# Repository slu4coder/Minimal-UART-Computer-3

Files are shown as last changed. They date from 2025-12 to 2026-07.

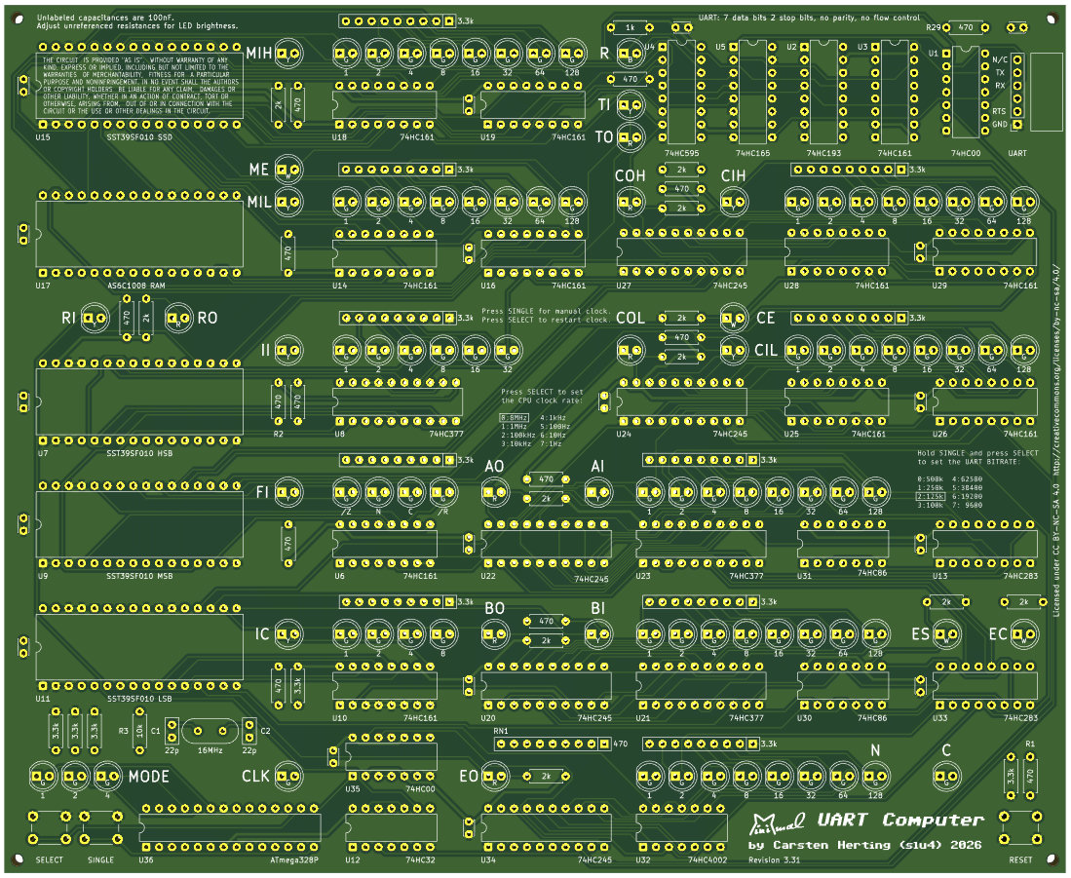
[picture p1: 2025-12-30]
Layout.jpg

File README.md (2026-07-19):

# Minimal UART Computer 3 - Blinkenlights!

Here comes a big update of my DIY 'Minimal UART Computer', a machine built around a serial interface just from a handful of logic ICs, RAM and FLASH memory. For it's size, simplicity and self-imposed limitations, it's got double the processing power of a Commodore C64 or Apple II. It's mission is to be a fun learning platform for understanding computers on a fundamental level.

Minimal_UART_3

This is a free and non-commercial project. I am in no way associated with any activies selling the 'Minimal UART Computer' as a product. Any such activity represents a license violation. Individual licenses apply for hardware and software parts. Please refer to the applicable documentations for detailed licensing information. 

● Manual: https://docs.google.com/document/d/1nIM-WRrVe7SzYY-DS1jcVHC4TCuIhlQ6LCHnZnEml7k/edit?usp=sharing

● The Minimal UART Computer has a dedicated hardware serial 'Minimal Terminal': https://github.com/slu4coder/Minimal-Terminal
but can also be operated via a USB-to-serial breakout board and a terminal emulation (e. g. Tera Term) of cause.
  
OVERVIEW:

● Textbook 'Von-Neumann' architecture, 8-bit data bus, 16-bit address bus

● 64 instructions (conditional branching, subroutines, stack and word operations)

● 32KB RAM, 32KB SSD with file system (format, load, save, dir, delete, defrag, ...)

● Adjustable UART I/O (7 data bits, 2 stop bits, 9600bps – 500000bps)

● Adjustable CPU clock speed (single step – 8MHz)

● Processing power ~1.1Mips @ 8MHz comparable to 2x Commodore 64 or 2x Apple II

● Clear(est?) and simple(st? – you judge!) design

● ALU with 2 data registers A & B

● 3 flags (zero, negative, carry)

● 24 control signals

● Only 30(!) 74HCxx logic ICs, RAM and FLASH (an ATmega328p is used as a variable clock generator)

● NEW: Blinkenlights ;-)

● Operating system wiht native assembler and editor

● Games and demos (Tetris, Mandelbrot)

● Cycle-exact emulator, cross-assembler (Win64 and Linux)

I hope you find this information useful, educational or otherwise interesting. I'd love to hear about your build, so meet me on YouTube:

https://www.youtube.com/watch?v=wpls_rTcvJ8

https://www.youtube.com/channel/UCXYQcMpUBT3aaQKfmAVJNow

This is a free and non-commercial project. I am in no way associated with any activies selling this as a product.
Any such activity represents a license violation. Individual licenses apply for hardware and software parts. Please refer to the
appropriate documentations for detailed licensing information.

See https://github.com/slu4coder/Minimal-64x4-Home-Computer for a more feature-rich alternative with bitmap graphics, VGA and PS/2.

If you like this project and want to give something back, you can do so via PayPal. Thanks!

https://paypal.me/CarstenHerting

Have fun!

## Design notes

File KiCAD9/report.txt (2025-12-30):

Plot in "/home/slu4/Dokumente/KiCAD/Minimal CPU 3.3 Tiny LED KiCAD9/gerbers/8-Bit CPU 32k-F_Cu.gtl" geschrieben.
Plot in "/home/slu4/Dokumente/KiCAD/Minimal CPU 3.3 Tiny LED KiCAD9/gerbers/8-Bit CPU 32k-B_Cu.gbl" geschrieben.
Plot in "/home/slu4/Dokumente/KiCAD/Minimal CPU 3.3 Tiny LED KiCAD9/gerbers/8-Bit CPU 32k-F_Silkscreen.gto" geschrieben.
Plot in "/home/slu4/Dokumente/KiCAD/Minimal CPU 3.3 Tiny LED KiCAD9/gerbers/8-Bit CPU 32k-B_Silkscreen.gbo" geschrieben.
Plot in "/home/slu4/Dokumente/KiCAD/Minimal CPU 3.3 Tiny LED KiCAD9/gerbers/8-Bit CPU 32k-F_Mask.gts" geschrieben.
Plot in "/home/slu4/Dokumente/KiCAD/Minimal CPU 3.3 Tiny LED KiCAD9/gerbers/8-Bit CPU 32k-B_Mask.gbs" geschrieben.
Plot in "/home/slu4/Dokumente/KiCAD/Minimal CPU 3.3 Tiny LED KiCAD9/gerbers/8-Bit CPU 32k-Edge_Cuts.gm1" geschrieben.
Hinweis: Fertig.
Hinweis: Fertig.

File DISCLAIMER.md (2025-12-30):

IN THE FOLLOWING, ALL INFORMATION MADE AVAILABLE IN THIS REPOSITORY
'Minimal-UART-Computer-3' IS SUMMARIZED UNDER THE TERM "SOFTWARE".

THE SOFTWARE IS PROVIDED "AS IS", WITHOUT WARRANTY OF ANY KIND, EXPRESS OR
IMPLIED, INCLUDING BUT NOT LIMITED TO THE WARRANTIES OF MERCHANTABILITY,
FITNESS FOR A PARTICULAR PURPOSE AND NONINFRINGEMENT. IN NO EVENT SHALL THE
AUTHORS BE LIABLE FOR ANY CLAIM, DAMAGES OR OTHER LIABILITY, WHETHER IN AN
ACTION OF CONTRACT, TORT OR OTHERWISE, ARISING FROM, OUT OF OR IN CONNECTION
WITH THE SOFTWARE OR THE USE OR OTHER DEALINGS IN THE SOFTWARE.

THE 'Minimal-UART-Computer-3' MIGHT UNINTENTIONALLY INTERFERE WITH RADIO
SIGNALS OR DISTURB OTHER ELECTRONIC DEVICES. USE THIS DEVICE FOR EDUCATIONAL
PURPOSES ONLY AND DON’T EMBED IT IN ANOTHER PRODUCT.

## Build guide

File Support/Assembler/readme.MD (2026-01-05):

See 'Emulator/src' section for assembler source code 'asm.cpp' and 'asm.h'.

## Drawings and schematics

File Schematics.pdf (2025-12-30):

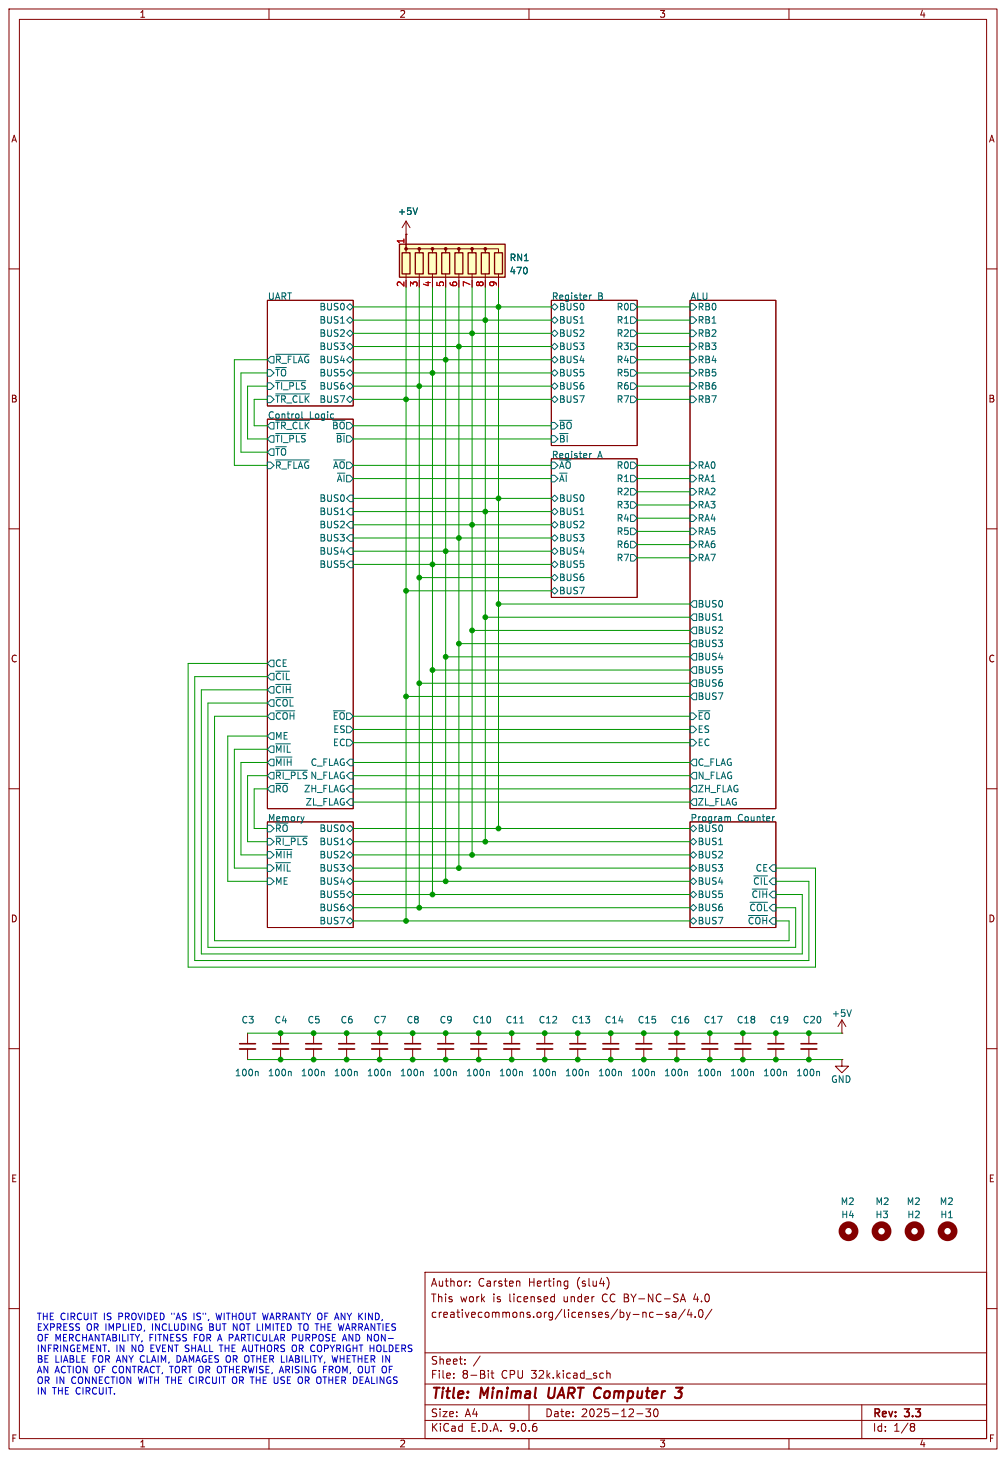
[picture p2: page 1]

~{COL} BUS3 BUS1 BUS0 BUS2 BUS4 BUS6 BUS7 BUS5 Program Counter BUS0 BUS1 BUS2 BUS3 BUS4 BUS5 BUS6 BUS7 ~{AI}

100n THE CIRCUIT IS PROVIDED "AS IS", WITHOUT WARRANTY OF ANY KIND, EXPRESS OR IMPLIED, INCLUDING BUT NOT LIMITED TO THE WARRANTIES OF MERCHANTABILITY, FITNESS FOR A PARTICULAR PURPOSE AND NON-

INFRINGEMENT. IN NO EVENT SHALL THE AUTHORS OR COPYRIGHT HOLDERS
BE LIABLE FOR ANY CLAIM, DAMAGES OR OTHER LIABILITY, WHETHER IN
AN ACTION OF CONTRACT, TORT OR OTHERWISE, ARISING FROM, OUT OF OR IN CONNECTION WITH THE CIRCUIT OR THE USE OR OTHER DEALINGS

Id: 1/8 Title: Minimal UART Computer 3

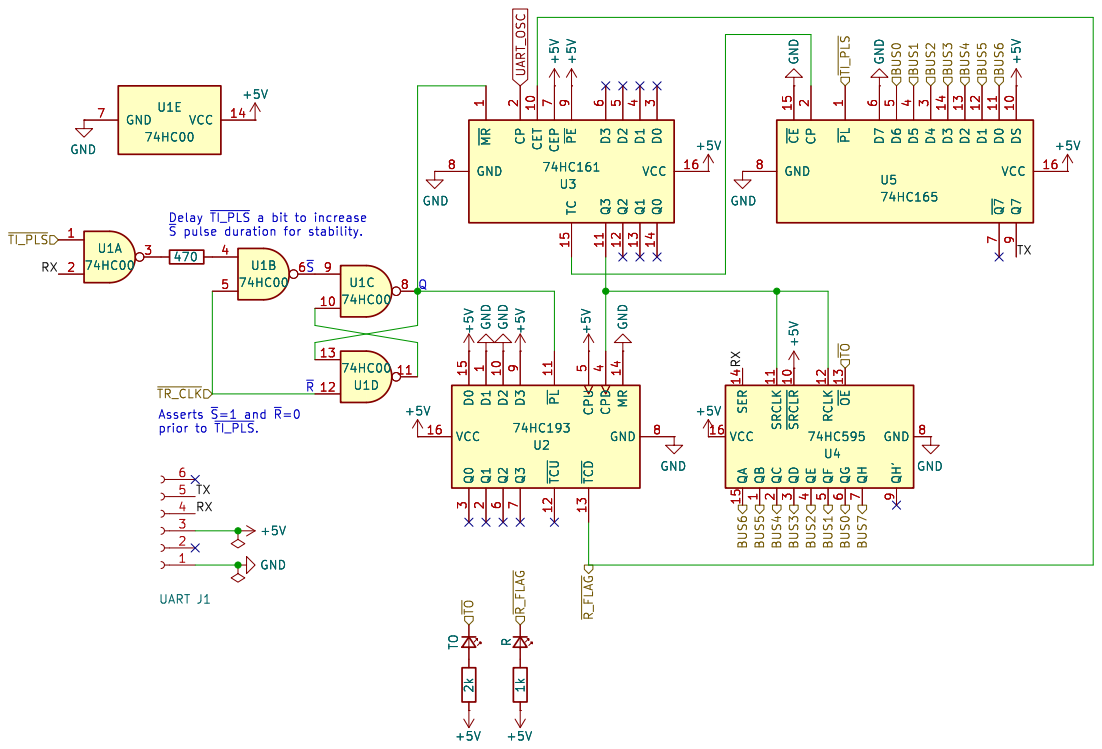
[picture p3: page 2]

2 ~{MR} 1 VCC 16 GND 8 Q0 14 Q1 13 Q2 12 Q3 11 TC 15 GND GND

2 ~{MR} 1 VCC 16 GND 8 Q0 14 Q1 13 Q2 12 Q3 11 TC 15 U3

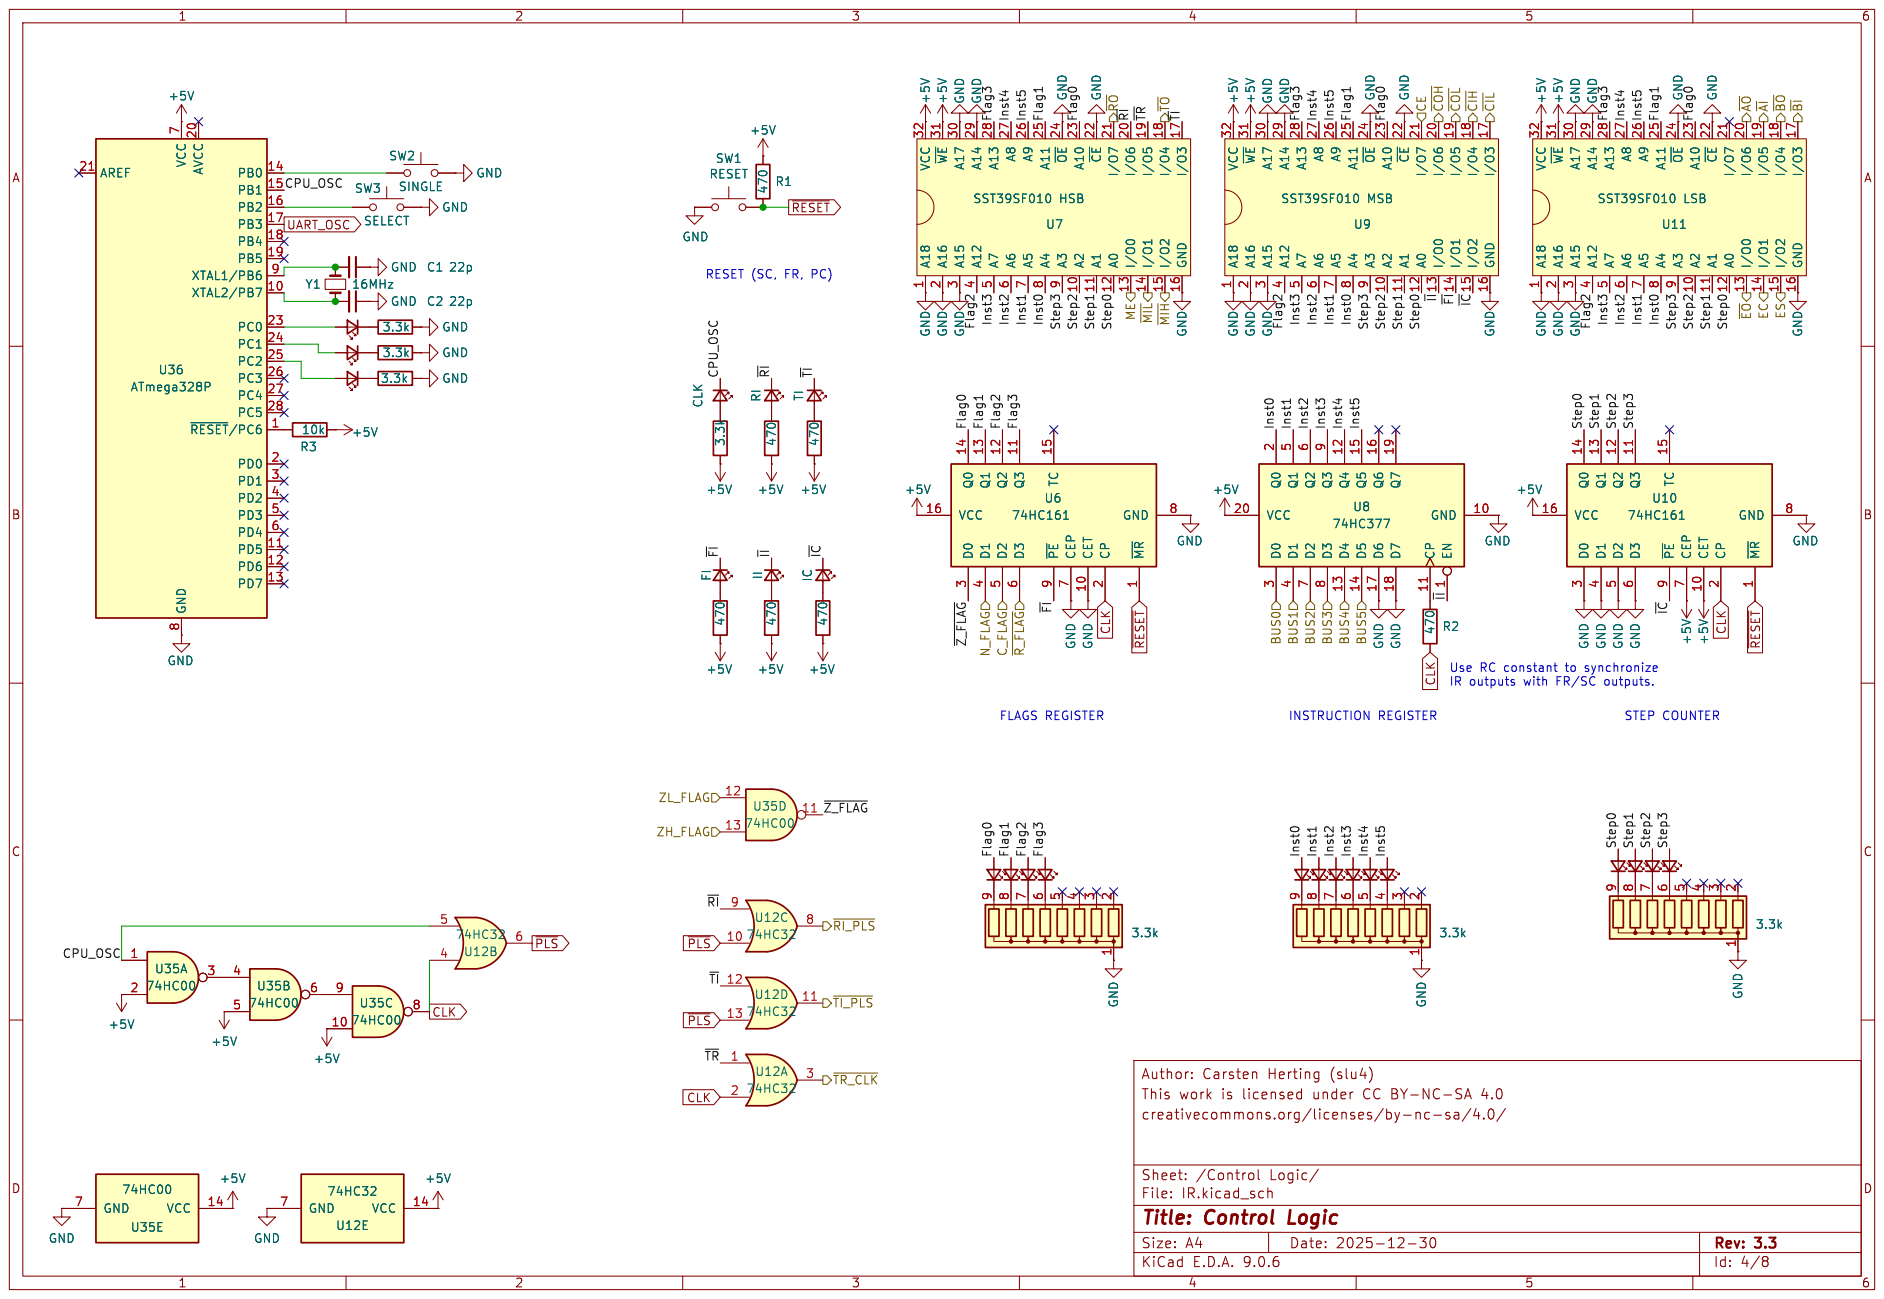
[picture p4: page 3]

9 A2 10 A1 11 A0 12 I/O0 13 I/O1 14 I/O2 15 GND 16 VCC 32 ~{WE}31 A17 30 A14 29 A13 28 A8 27 A9 26 A11 25 ~{OE}24 A10 23 ~{CE}22 I/O7 21 I/O6 20 I/O5 19 I/O4 18 I/O3 17 GND GND GND +5V +5V GND GND GND GND GND

9 Q4 12 Q5 15 Q6 16 Q7 19 GND GND GND GND GND +5V +5V GND GND

9 A2 10 A1 11 A0 12 I/O0 13 I/O1 14 I/O2 15 GND 16 VCC 32 ~{WE}31 A17 30 A14 29 A13 28 A8 27 A9 26 A11 25 ~{OE}24 A10 23 ~{CE}22 I/O7 21 I/O6 20 I/O5 19 I/O4 18 I/O3 17 U11 SST39SF010 LSB GND GND470 R2 GND GND RI SW1 RESET R1 470 +5V GND

9 A2 10 A1 11 A0 12 I/O0 13 I/O1 14 I/O2 15 GND 16 VCC 32 ~{WE}31 A17 30 A14 29 A13 28 A8 27 A9 26 A11 25 ~{OE}24 A10 23 ~{CE}22 I/O7 21 I/O6 20 I/O5 19 I/O4 18 I/O3 17 U7 SST39SF010 HSB GND

9 A2 10 A1 11 A0 12 I/O0 13 I/O1 14 I/O2 15 GND 16 VCC 32 ~{WE}31 A17 30 A14 29 A13 28 A8 27 A9 26 A11 25 ~{OE}24 A10 23 ~{CE}22 I/O7 21 I/O6 20 I/O5 19 I/O4 18 I/O3 17 GND GND470 R2 GND GND GND GND

9 A2 10 A1 11 A0 12 I/O0 13 I/O1 14 I/O2 15 GND 16 VCC 32 ~{WE}31 A17 30 A14 29 A13 28 A8 27 A9 26 A11 25 ~{OE}24 A10 23 ~{CE}22 I/O7 21 I/O6 20 I/O5 19 I/O4 18 I/O3 17 U9 SST39SF010 MSB D0

9 A2 10 A1 11 A0 12 I/O0 13 I/O1 14 I/O2 15 GND 16 VCC 32 ~{WE}31 A17 30 A14 29 A13 28 A8 27 A9 26 A11 25 ~{OE}24 A10 23 ~{CE}22 I/O7 21 I/O6 20 I/O5 19 I/O4 18 I/O3 17 U8

2 ~{MR} 1 VCC 16 GND 8 Q0 14 Q1 13 Q2 12 Q3 11 TC 15 +5V U36 ATmega328P

2 ~{MR} 1 VCC 16 GND 8 Q0 14 Q1 13 Q2 12 Q3 11 TC 15 U6

2 ~{MR} 1 VCC 16 GND 8 Q0 14 Q1 13 Q2 12 Q3 11 TC 15 U10

2 ~{MR} 1 VCC 16 GND 8 Q0 14 Q1 13 Q2 12 Q3 11 TC 15 +5V +5V GND

Id: 4/8 Title: Control Logic

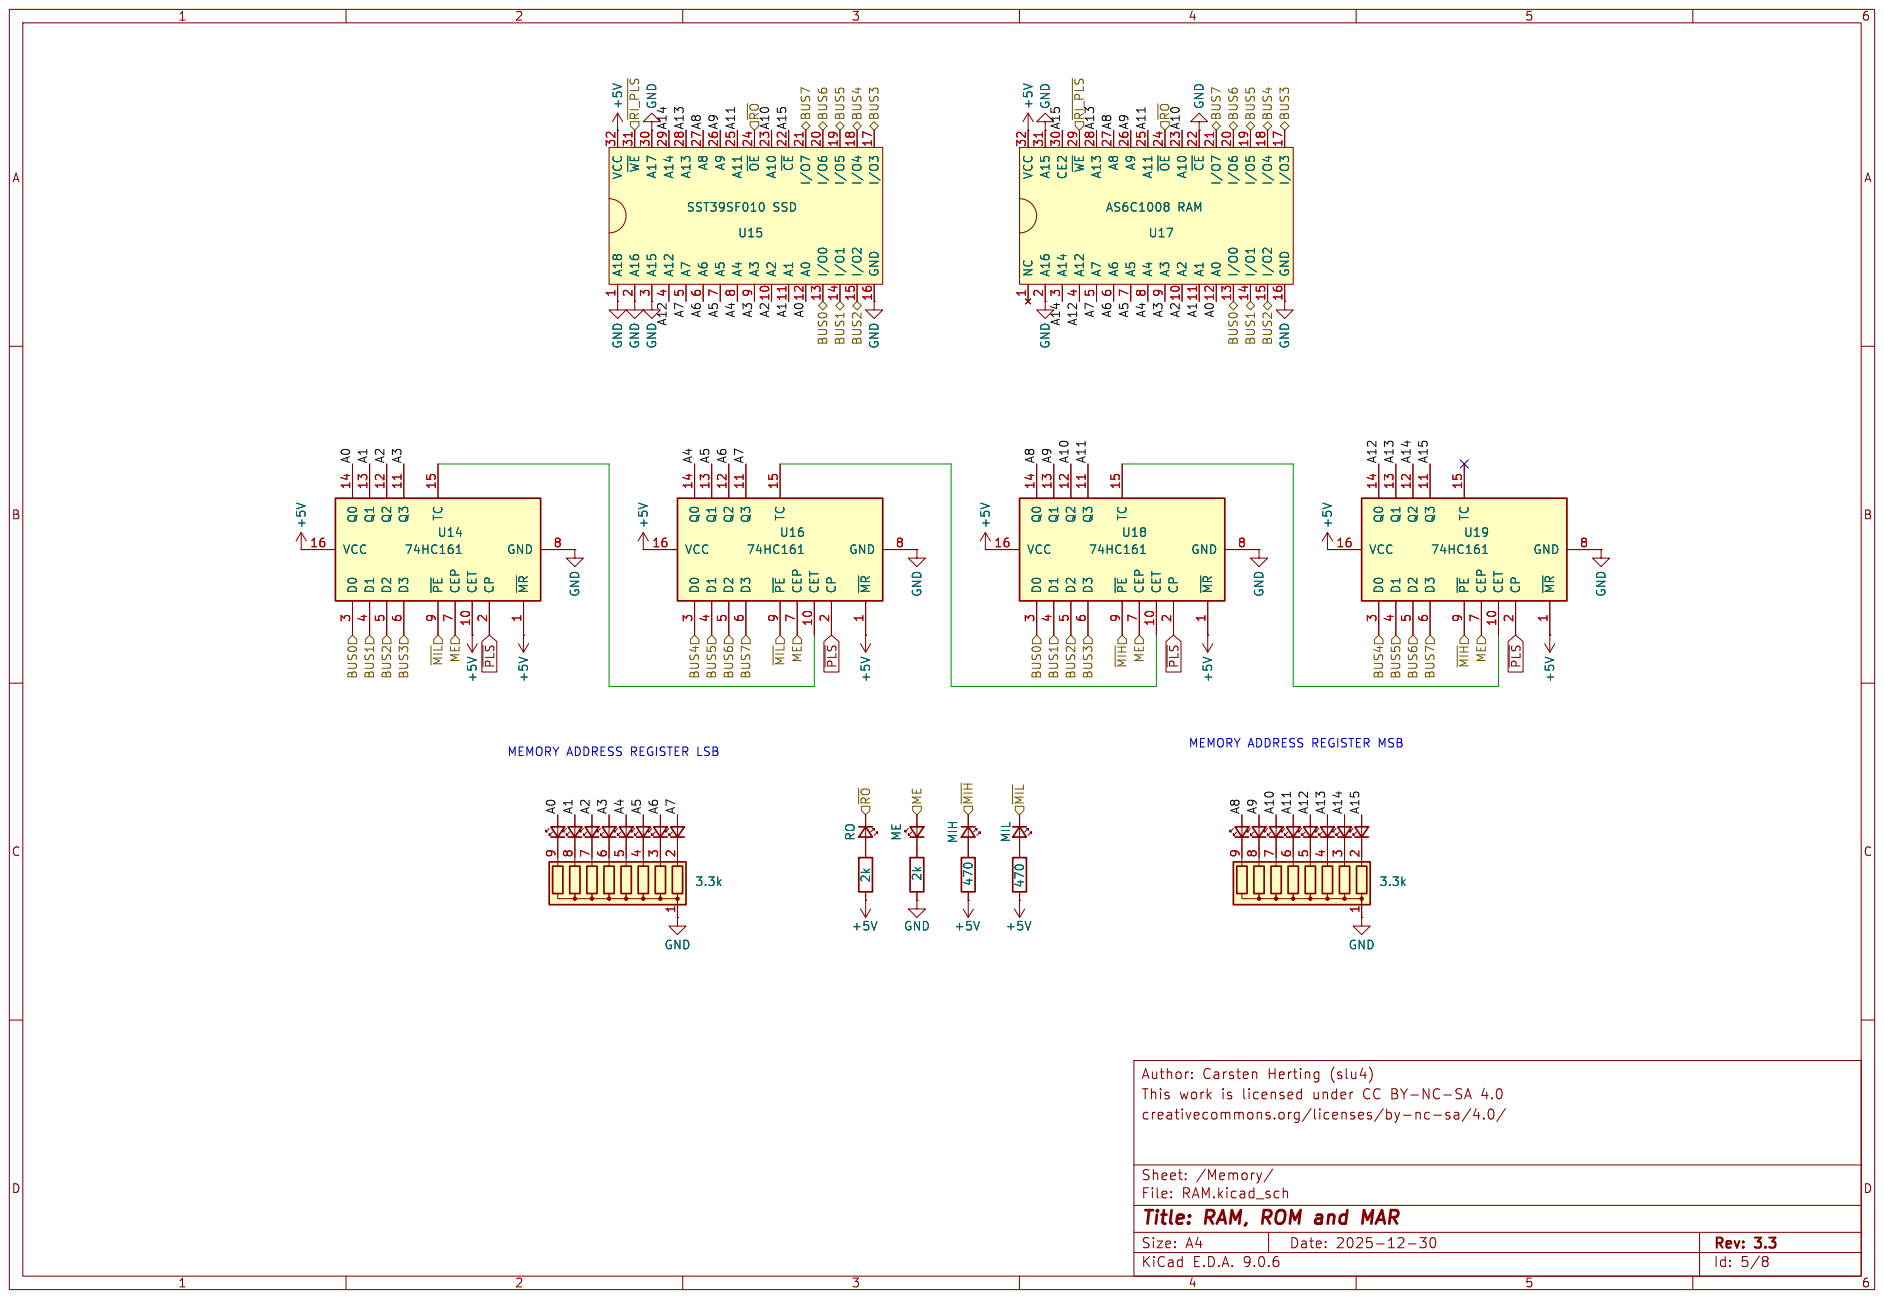
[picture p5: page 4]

9 A2 10 A1 11 A0 12 I/O0 13 I/O1 14 I/O2 15 GND 16 VCC 32 ~{WE}31 A17 30 A14 29 A13 28 A8 27 A9 26 A11 25 ~{OE}24 A10 23 ~{CE}22 I/O7 21 I/O6 20 I/O5 19 I/O4 18 I/O3 17 U15 SST39SF010 SSD +5V GND GND GND GND GND GND ~{RO} BUS6 BUS4 BUS1 BUS6 BUS3 ~{MIL} BUS0 BUS2 ~{RO} BUS3 ~{MIH} BUS1 BUS2 BUS1 BUS7 BUS4 BUS7 BUS5 ME BUS0 BUS1 BUS5 BUS3 ~{RI_PLS} BUS2 BUS5 BUS5 BUS6ME ~{MIH} BUS4 BUS7 ~{RI_PLS} BUS4 BUS6 BUS7 ~{RO} ME BUS0 BUS3 BUS0 BUS2 ~{MIL} ME ~{MIH} ME ~{MIL} ~{PLS} ~{PLS} ~{PLS} ~{PLS} A0A9A10 A11 A8A11 A6A4 A12A7A5A3A2 A5A6A7 A1A0 A4 A13 A8A9 A0 A15 A3A4 A14 A5A6 A12 A13 A1A2A7 A6 A14 A15 A8A9A10 A11 A12 A13 A14 A15 A4 A3 A7A0 A14 A12 A2 A10 A1 A10 A8A9A11 A1 A13 A3 A15 A5A2 MEMORY ADDRESS REGISTER MSB MEMORY ADDRESS REGISTER LSB +5V GND GND GND GND GND

2 ~{MR} 1 VCC 16 GND 8 Q0 14 Q1 13 Q2 12 Q3 11 TC 15 GND +5V GND GND GND

9 A2 10 A1 11 A0 12 I/O0 13 I/O1 14 I/O2 15 GND 16 VCC 32 A15 31 CE2 30 ~{WE}29 A13 28 A8 27 A9 26 A11 25 ~{OE}24 A10 23 ~{CE}22 I/O7 21 I/O6 20 I/O5 19 I/O4 18 I/O3 17 U17 AS6C1008 RAMGND A18

9 A2 10 A1 11 A0 12 I/O0 13 I/O1 14 I/O2 15 GND 16 VCC 32 ~{WE}31 A17 30 A14 29 A13 28 A8 27 A9 26 A11 25 ~{OE}24 A10 23 ~{CE}22 I/O7 21 I/O6 20 I/O5 19 I/O4 18 I/O3 17 GND +5V +5V U19

9 A2 10 A1 11 A0 12 I/O0 13 I/O1 14 I/O2 15 GND 16 VCC 32 A15 31 CE2 30 ~{WE}29 A13 28 A8 27 A9 26 A11 25 ~{OE}24 A10 23 ~{CE}22 I/O7 21 I/O6 20 I/O5 19 I/O4 18 I/O3 17 MIL 470 470 +5V MIH

2 ~{MR} 1 VCC 16 GND 8 Q0 14 Q1 13 Q2 12 Q3 11 TC 15 +5V GND +5V +5V GND +5V +5V U14

2 ~{MR} 1 VCC 16 GND 8 Q0 14 Q1 13 Q2 12 Q3 11 TC 15 U14

2 ~{MR} 1 VCC 16 GND 8 Q0 14 Q1 13 Q2 12 Q3 11 TC 15 U16

2 ~{MR} 1 VCC 16 GND 8 Q0 14 Q1 13 Q2 12 Q3 11 TC 15 GND +5V GND2k ROME

2 ~{MR} 1 VCC 16 GND 8 Q0 14 Q1 13 Q2 12 Q3 11 TC 15 +5V U16

2 ~{MR} 1 VCC 16 GND 8 Q0 14 Q1 13 Q2 12 Q3 11 TC 15 U18

2 ~{MR} 1 VCC 16 GND 8 Q0 14 Q1 13 Q2 12 Q3 11 TC 15 U19

File: RAM.kicad_sch Sheet: /Memory/
Id: 5/8 Title: RAM, ROM and MAR

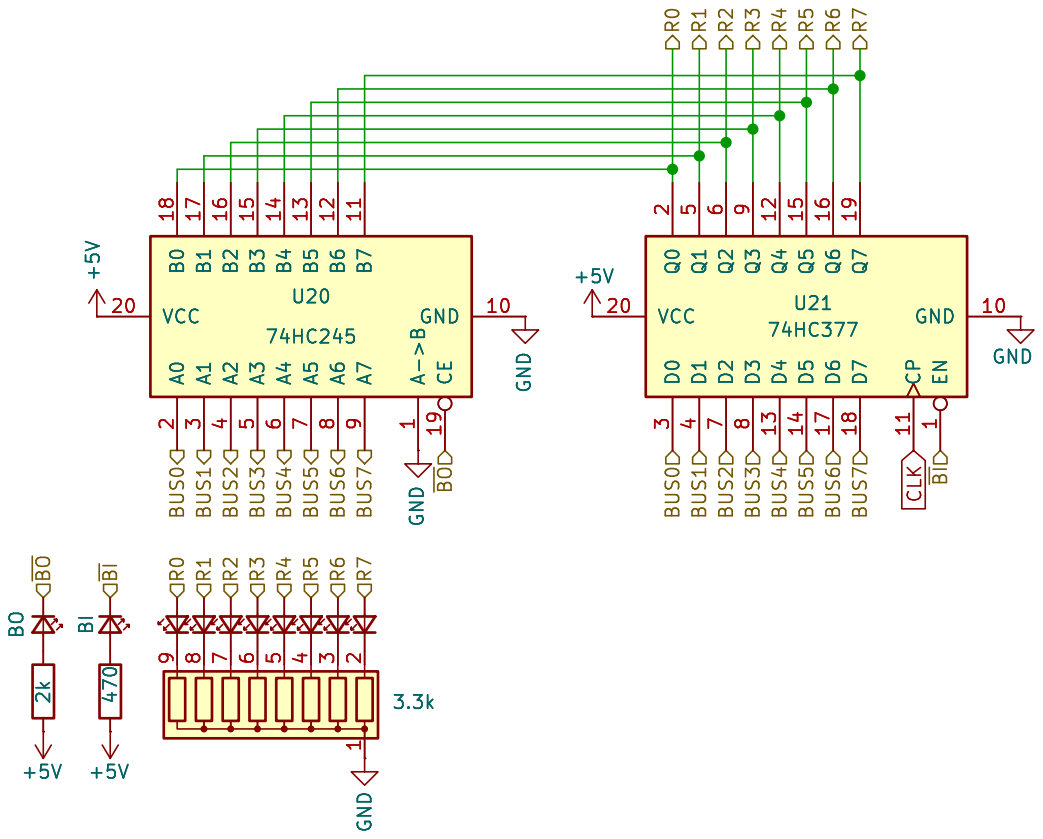
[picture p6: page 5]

1 CE 19 VCC 20 GND 10 B0 18 B1 17 B2 16 B3 15 B4 14 B5 13 B6 12 B7 11 +5V GND 2k470 BO +5V BI +5V GND

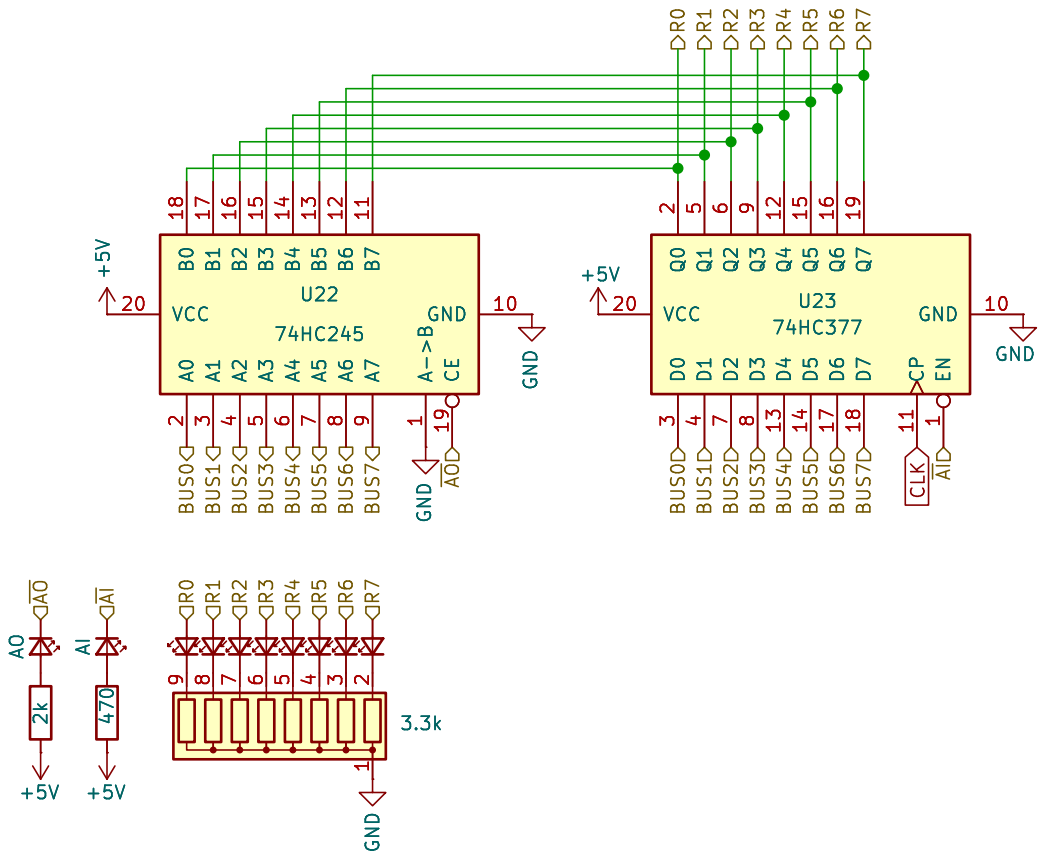
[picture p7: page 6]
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

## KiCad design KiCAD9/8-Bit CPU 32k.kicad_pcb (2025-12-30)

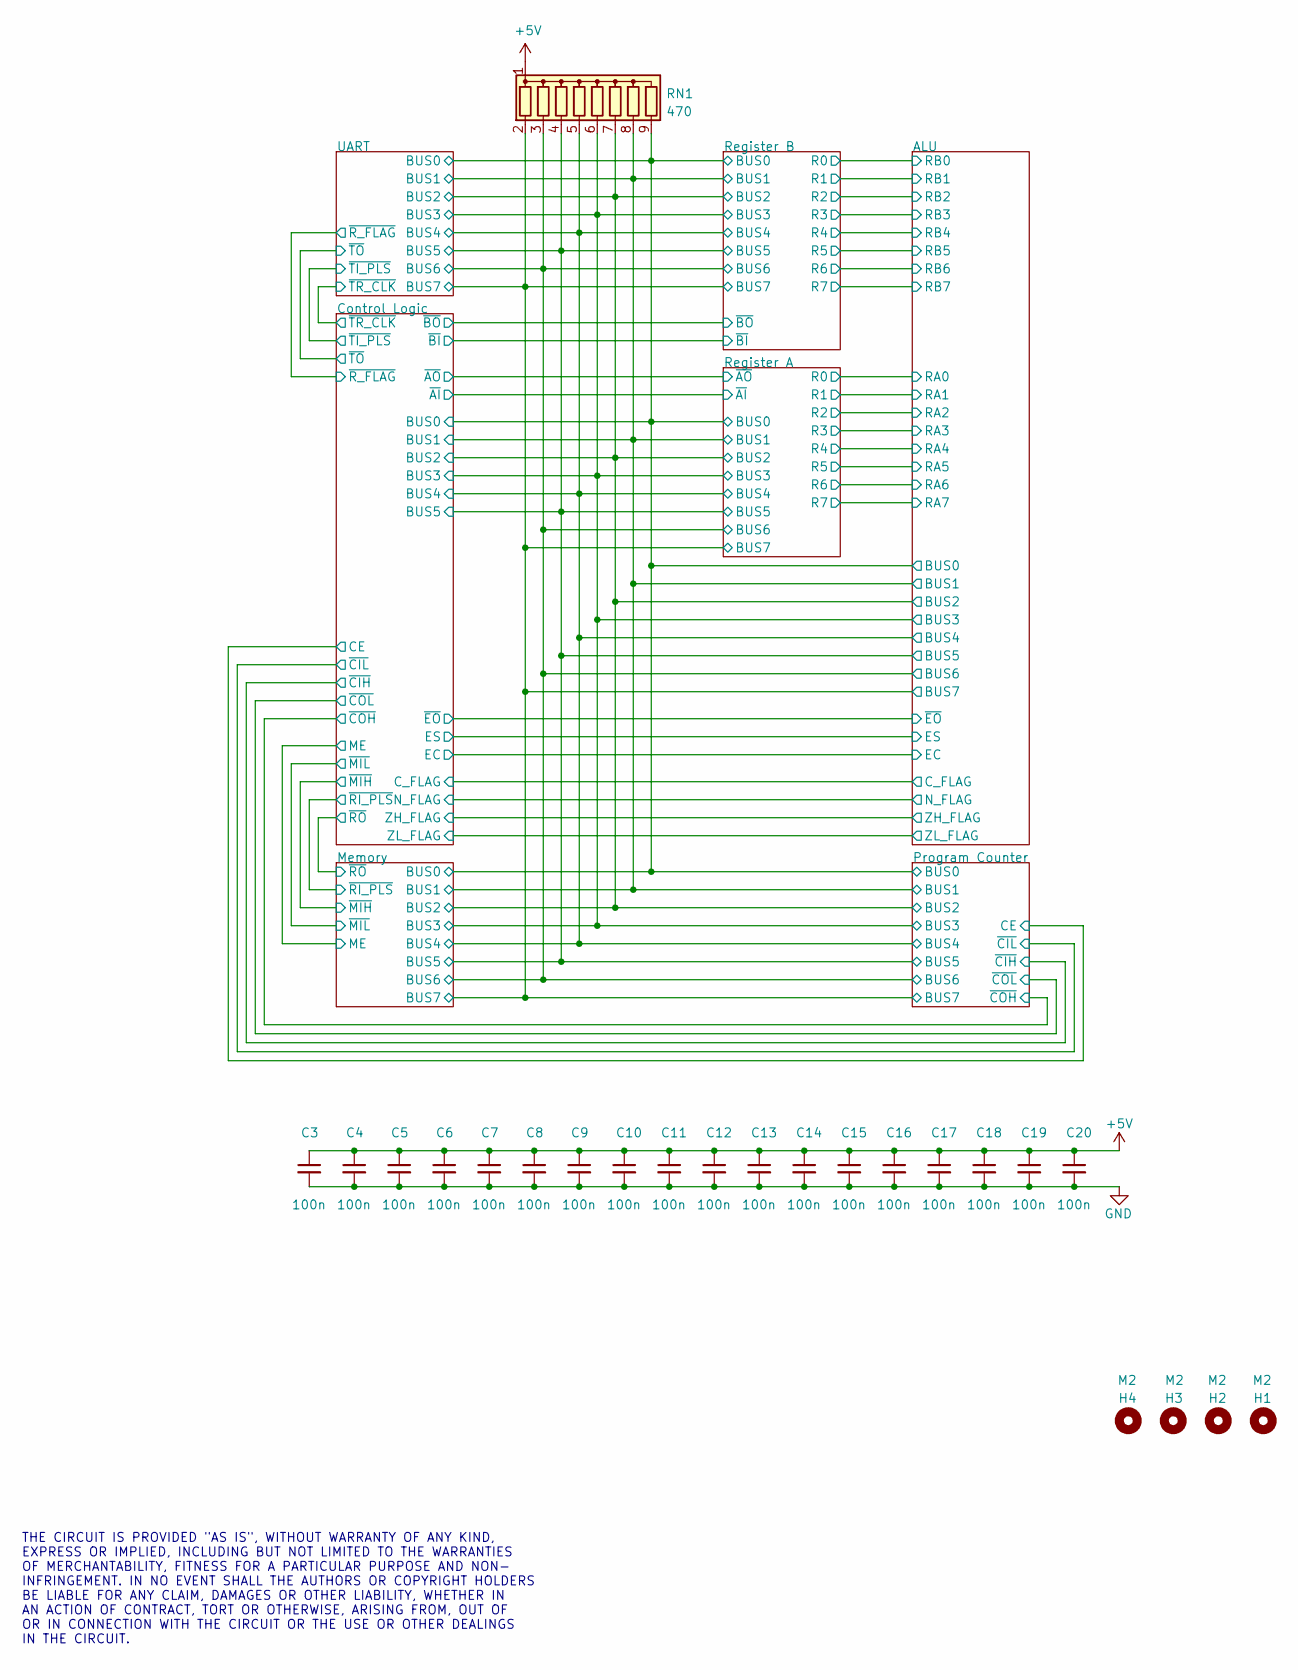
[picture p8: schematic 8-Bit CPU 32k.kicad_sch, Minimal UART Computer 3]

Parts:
C3, C4, C5, C6, C7, C8, C9, C10, C11, C12, C13, C14, C15, C16, C17, C18, C19, C20: 100n; C_Disc_D3.0mm_W2.0mm_P2.50mm
H1, H2, H3, H4: M2; MountingHole_2.2mm_M2
RN1: 470; R_Array_SIP9

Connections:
+5V: C3.1, C4.1, C5.1, C6.1, C7.1, C8.1, C9.1, C10.1, C11.1, C12.1, C13.1, C14.1, C15.1, C16.1, C17.1, C18.1, C19.1, C20.1, RN1.1 (common); also elsewhere on the board
/ALU/BUS0: RN1.9 (R8); also elsewhere on the board
/ALU/BUS1: RN1.8 (R7); also elsewhere on the board
/ALU/BUS2: RN1.7 (R6); also elsewhere on the board
/ALU/BUS3: RN1.6 (R5); also elsewhere on the board
/ALU/BUS4: RN1.5 (R4); also elsewhere on the board
/ALU/BUS5: RN1.4 (R3); also elsewhere on the board
/ALU/BUS6: RN1.3 (R2); also elsewhere on the board
/ALU/BUS7: RN1.2 (R1); also elsewhere on the board
GND: C3.2, C4.2, C5.2, C6.2, C7.2, C8.2, C9.2, C10.2, C11.2, C12.2, C13.2, C14.2, C15.2, C16.2, C17.2, C18.2, C19.2, C20.2; also elsewhere on the board

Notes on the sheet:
THE CIRCUIT IS PROVIDED "AS IS", WITHOUT WARRANTY OF ANY KIND, EXPRESS OR IMPLIED, INCLUDING BUT NOT LIMITED TO THE WARRANTIES OF MERCHANTABILITY, FITNESS FOR A PARTICULAR PURPOSE AND NON- INFRINGEMENT. IN NO EVENT SHALL THE AUTHORS OR COPYRIGHT HOLDERS BE LIABLE FOR ANY CLAIM, DAMAGES OR OTHER LIA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

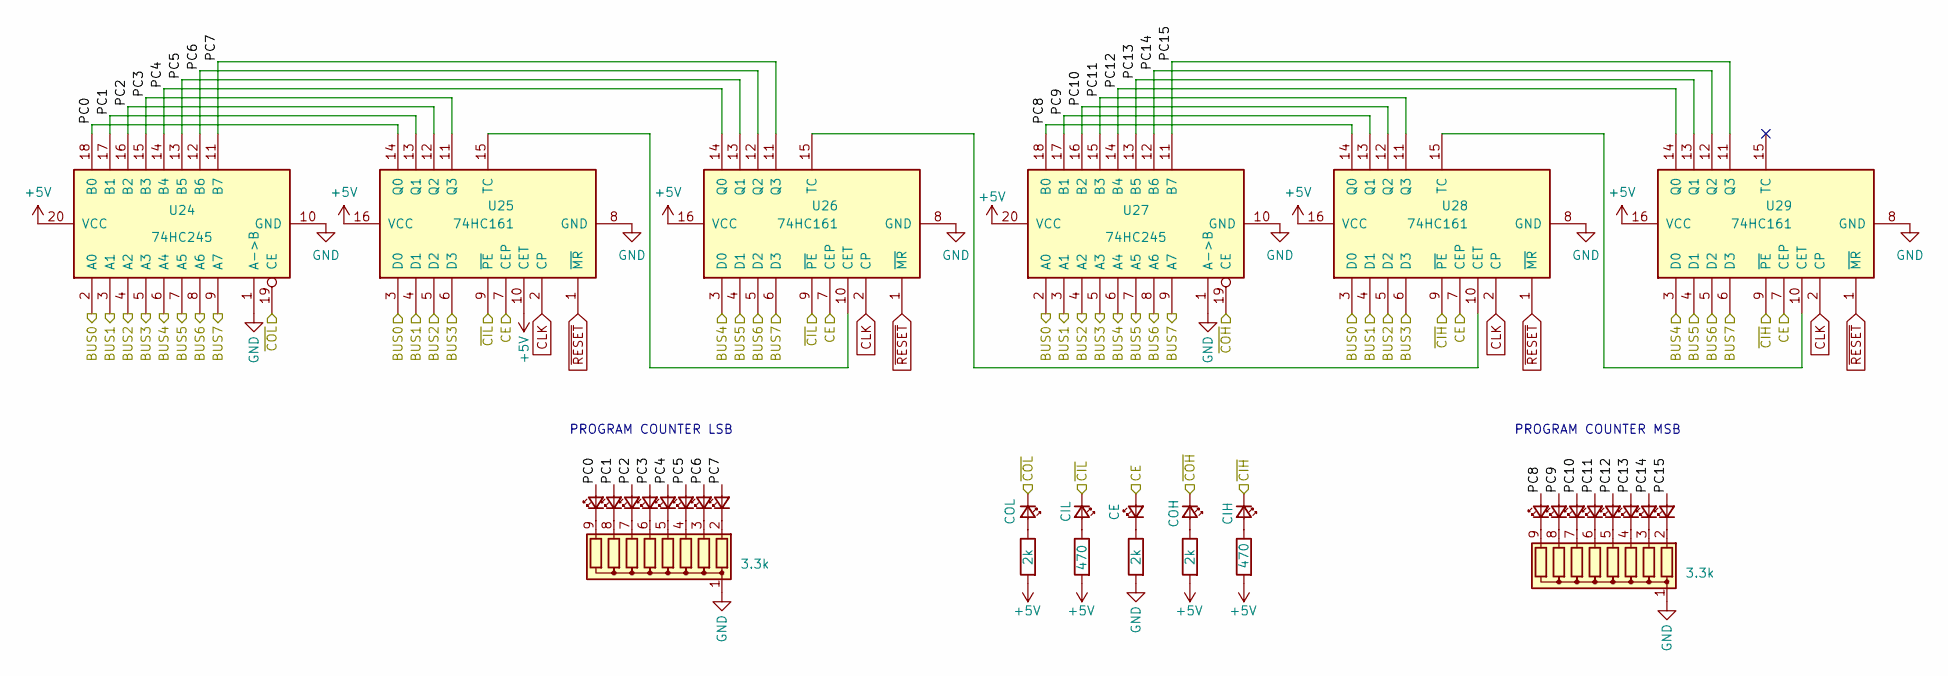
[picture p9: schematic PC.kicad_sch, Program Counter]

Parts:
D20, D21, D22, D23, D24, D25, D26, D27, D28, D29, D30, D31, D32, D33, D34, D35: LED_Small; LED_D5.0mm
D79: CIH; LED_D5.0mm
D81: COH; LED_D5.0mm
D83: COL; LED_D5.0mm
D84: CIL; LED_D5.0mm
D92: CE; LED_D5.0mm
R12, R17: 470; R_Axial_DIN0207_L6.3mm_D2.5mm_P7.62mm_Horizontal
R14, R16, R25: 2k; R_Axial_DIN0207_L6.3mm_D2.5mm_P7.62mm_Horizontal
RN4, RN5: 3.3k; R_Array_SIP9
U24, U27: 74HC245; DIP-20_W7.62mm
U25, U26, U28, U29: 74HC161; DIP-16_W7.62mm

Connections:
+5V: R12.2, R14.2, R16.2, R17.2, U24.20 (VCC), U25.10 (CET), U25.16 (VCC), U26.16 (VCC), U27.20 (VCC), U28.16 (VCC), U29.16 (VCC); also elsewhere on the board
/ALU/BUS0: U24.2 (A0), U25.3 (D0), U27.2 (A0), U28.3 (D0); also elsewhere on the board
/ALU/BUS1: U24.3 (A1), U25.4 (D1), U27.3 (A1), U28.4 (D1); also elsewhere on the board
/ALU/BUS2: U24.4 (A2), U25.5 (D2), U27.4 (A2), U28.5 (D2); also elsewhere on the board
/ALU/BUS3: U24.5 (A3), U25.6 (D3), U27.5 (A3), U28.6 (D3); also elsewhere on the board
/ALU/BUS4: U24.6 (A4), U26.3 (D0), U27.6 (A4), U29.3 (D0); also elsewhere on the board
/ALU/BUS5: U24.7 (A5), U26.4 (D1), U27.7 (A5), U29.4 (D1); also elsewhere on the board
/ALU/BUS6: U24.8 (A6), U26.5 (D2), U27.8 (A6), U29.5 (D2); also elsewhere on the board
/ALU/BUS7: U24.9 (A7), U26.6 (D3), U27.9 (A7), U29.6 (D3); also elsewhere on the board
/Control Logic/CE: D92.2 (A), U25.7 (CEP), U26.7 (CEP), U28.7 (CEP), U29.7 (CEP); also elsewhere on the board
/Control Logic/~CIH: D79.1 (K), U28.9 (~PE), U29.9 (~PE); also elsewhere on the board
/Control Logic/~CIL: D84.1 (K), U25.9 (~PE), U26.9 (~PE); also elsewhere on the board
/Control Logic/~COH: D81.1 (K), U27.19 (CE); also elsewhere on the board
/Control Logic/~COL: D83.1 (K), U24.19 (CE); also elsewhere on the board
/Program Counter/PC0: D20.2 (A), U24.18 (B0), U25.14 (Q0)
/Program Counter/PC1: D21.2 (A), U24.17 (B1), U25.13 (Q1)
/Program Counter/PC2: D22.2 (A), U24.16 (B2), U25.12 (Q2)
/Program Counter/PC3: D23.2 (A), U24.15 (B3), U25.11 (Q3)
/Program Counter/PC4: D24.2 (A), U24.14 (B4), U26.14 (Q0)
/Program Counter/PC5: D25.2 (A), U24.13 (B5), U26.13 (Q1)
/Program Counter/PC6: D26.2 (A), U24.12 (B6), U26.12 (Q2)
/Program Counter/PC7: D27.2 (A), U24.11 (B7), U26.11 (Q3)
/Program Counter/PC8: D28.2 (A), U27.18 (B0), U28.14 (Q0)
/Program Counter/PC9: D29.2 (A), U27.17 (B1), U28.13 (Q1)
/Program Counter/PC10: D30.2 (A), U27.16 (B2), U28.12 (Q2)
/Program Counter/PC11: D31.2 (A), U27.15 (B3), U28.11 (Q3)
/Program Counter/PC12: D32.2 (A), U27.14 (B4), U29.14 (Q0)
/Program Counter/PC13: D33.2 (A), U27.13 (B5), U29.13 (Q1)
/Program Counter/PC14: D34.2 (A), U27.12 (B6), U29.12 (Q2)
/Program Counter/PC15: D35.2 (A), U27.11 (B7), U29.11 (Q3)
CLK: U25.2 (CP), U26.2 (CP), U28.2 (CP), U29.2 (CP); also elsewhere on the board
GND: R25.2, RN4.1 (common), RN5.1 (common), U24.1 (A->B), U24.10 (GND), U25.8 (GND), U26.8 (GND), U27.1 (A->B), U27.10 (GND), U28.8 (GND), U29.8 (GND); also elsewhere on the board
unnamed: D20.1 (K), RN4.9 (R8)
unnamed: D21.1 (K), RN4.8 (R7)
unnamed: D22.1 (K), RN4.7 (R6)
unnamed: D23.1 (K), RN4.6 (R5)
unnamed: D24.1 (K), RN4.5 (R4)
unnamed: D25.1 (K), RN4.4 (R3)
unnamed: D26.1 (K), RN4.3 (R2)
unnamed: D27.1 (K), RN4.2 (R1)
unnamed: D28.1 (K), RN5.9 (R8)
unnamed: D29.1 (K), RN5.8 (R7)
unnamed: D30.1 (K), RN5.7 (R6)
unnamed: D31.1 (K), RN5.6 (R5)
unnamed: D32.1 (K), RN5.5 (R4)
unnamed: D33.1 (K), RN5.4 (R3)
unnamed: D34.1 (K), RN5.3 (R2)
unnamed: D35.1 (K), RN5.2 (R1)
unnamed: D79.2 (A), R12.1
unnamed: D81.2 (A), R14.1
unnamed: D83.2 (A), R16.1
unnamed: D84.2 (A), R17.1
unnamed: D92.1 (K), R25.1
unnamed: U25.15 (TC), U26.10 (CET)
unnamed: U26.15 (TC), U28.10 (CET)
unnamed: U28.15 (TC), U29.10 (CET)
~RESET: U25.1 (~MR), U26.1 (~MR), U28.1 (~MR), U29.1 (~MR); also elsewhere on the board

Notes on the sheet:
PROGRAM COUNTER MSB
PROGRAM COUNTER LSB

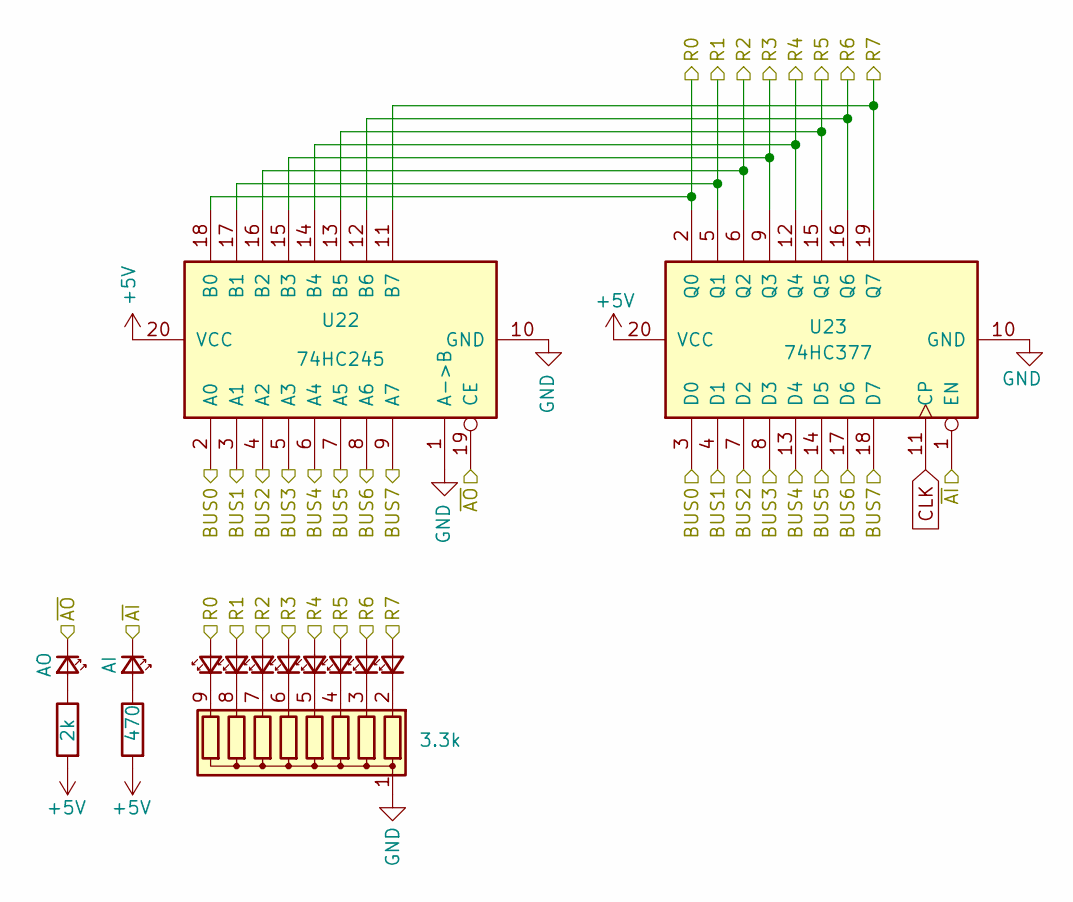
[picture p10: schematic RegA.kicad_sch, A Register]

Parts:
D36, D37, D38, D39, D40, D41, D42, D43: LED_Small; LED_D5.0mm
D65: AI; LED_D5.0mm
D66: AO; LED_D5.0mm
R7: 470; R_Axial_DIN0207_L6.3mm_D2.5mm_P7.62mm_Horizontal
R8: 2k; R_Axial_DIN0207_L6.3mm_D2.5mm_P7.62mm_Horizontal
RN6: 3.3k; R_Array_SIP9
U22: 74HC245; DIP-20_W7.62mm
U23: 74HC377; DIP-20_W7.62mm

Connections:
+5V: R7.2, R8.2, U22.20 (VCC), U23.20 (VCC); also elsewhere on the board
/ALU/BUS0: U22.2 (A0), U23.3 (D0); also elsewhere on the board
/ALU/BUS1: U22.3 (A1), U23.4 (D1); also elsewhere on the board
/ALU/BUS2: U22.4 (A2), U23.7 (D2); also elsewhere on the board
/ALU/BUS3: U22.5 (A3), U23.8 (D3); also elsewhere on the board
/ALU/BUS4: U22.6 (A4), U23.13 (D4); also elsewhere on the board
/ALU/BUS5: U22.7 (A5), U23.14 (D5); also elsewhere on the board
/ALU/BUS6: U22.8 (A6), U23.17 (D6); also elsewhere on the board
/ALU/BUS7: U22.9 (A7), U23.18 (D7); also elsewhere on the board
/ALU/RA0: D36.2 (A), U22.18 (B0), U23.2 (Q0); also elsewhere on the board
/ALU/RA1: D37.2 (A), U22.17 (B1), U23.5 (Q1); also elsewhere on the board
/ALU/RA2: D38.2 (A), U22.16 (B2), U23.6 (Q2); also elsewhere on the board
/ALU/RA3: D39.2 (A), U22.15 (B3), U23.9 (Q3); also elsewhere on the board
/ALU/RA4: D40.2 (A), U22.14 (B4), U23.12 (Q4); also elsewhere on the board
/ALU/RA5: D41.2 (A), U22.13 (B5), U23.15 (Q5); also elsewhere on the board
/ALU/RA6: D42.2 (A), U22.12 (B6), U23.16 (Q6); also elsewhere on the board
/ALU/RA7: D43.2 (A), U22.11 (B7), U23.19 (Q7); also elsewhere on the board
/Control Logic/~AI: D65.1 (K), U23.1 (EN); also elsewhere on the board
/Control Logic/~AO: D66.1 (K), U22.19 (CE); also elsewhere on the board
CLK: U23.11 (CP); also elsewhere on the board
GND: RN6.1 (common), U22.1 (A->B), U22.10 (GND), U23.10 (GND); also elsewhere on the board
unnamed: D36.1 (K), RN6.9 (R8)
unnamed: D37.1 (K), RN6.8 (R7)
unnamed: D38.1 (K), RN6.7 (R6)
unnamed: D39.1 (K), RN6.6 (R5)
unnamed: D40.1 (K), RN6.5 (R4)
unnamed: D41.1 (K), RN6.4 (R3)
unnamed: D42.1 (K), RN6.3 (R2)
unnamed: D43.1 (K), RN6.2 (R1)
unnamed: D65.2 (A), R7.1
unnamed: D66.2 (A), R8.1

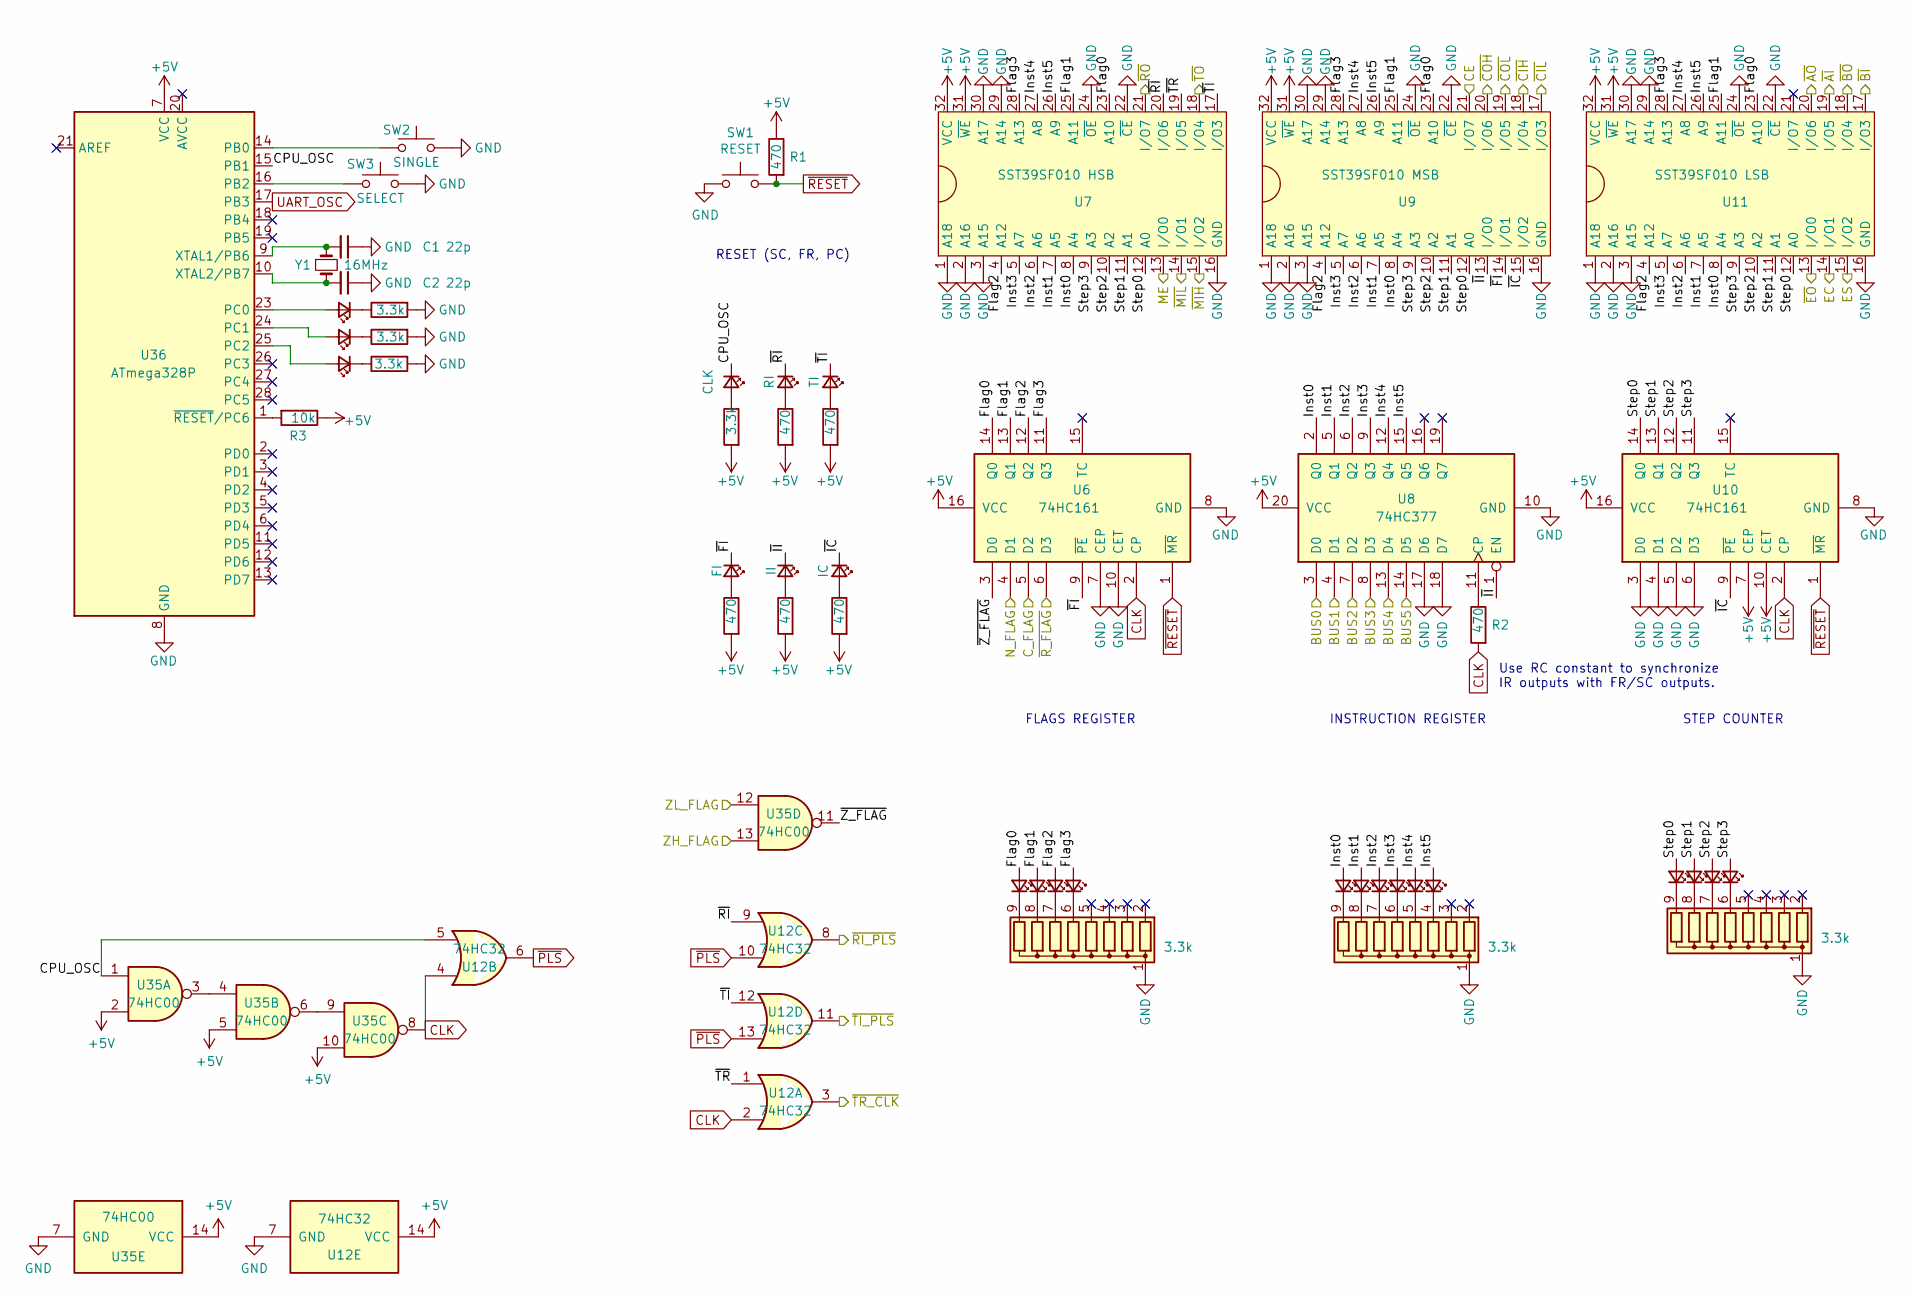
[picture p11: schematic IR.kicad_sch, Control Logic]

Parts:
C1, C2: 22p; C_Disc_D5.0mm_W2.5mm_P2.50mm
D1, D2, D3: LED_small; LED_D5.0mm
D60, D61, D62, D63, D64, D67, D68, D69, D70, D71, D72, D73, D74, D75: LED_Small; LED_D5.0mm
D82: RI; LED_D5.0mm
D87: TI; LED_D5.0mm
D89: FI; LED_D5.0mm
D90: II; LED_D5.0mm
D91: IC; LED_D5.0mm
D100: CLK; LED_D5.0mm
R1, R2, R15, R20, R22, R23, R24: 470; R_Axial_DIN0207_L6.3mm_D2.5mm_P7.62mm_Horizontal
R3: 10k; R_Axial_DIN0207_L6.3mm_D2.5mm_P7.62mm_Horizontal
R4, R5, R6, R33: 3.3k; R_Axial_DIN0207_L6.3mm_D2.5mm_P7.62mm_Horizontal
RN9, RN10, RN11: 3.3k; R_Array_SIP9
SW1: RESET; SW_PUSH_6mm
SW2: SINGLE; SW_PUSH_6mm
SW3: SELECT; SW_PUSH_6mm
U6, U10: 74HC161; DIP-16_W7.62mm
U7: SST39SF010 HSB; DIP-32_W15.24mm
U8: 74HC377; DIP-20_W7.62mm
U9: SST39SF010 MSB; DIP-32_W15.24mm
U11: SST39SF010 LSB; DIP-32_W15.24mm
U12: 74HC32; DIP-14_W7.62mm
U35: 74HC00; DIP-14_W7.62mm
U36: ATmega328P; DIP-28_W7.62mm
Y1: 16MHz; Crystal_HC18-U_Vertical

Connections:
+5V: R1.1, R3.1, R15.2, R20.2, R22.2, R23.2, R24.2, R33.2, U6.16 (VCC), U7.31 (~WE), U7.32 (VCC), U8.20 (VCC), U9.31 (~WE), U9.32 (VCC), U10.7 (CEP), U10.10 (CET), U10.16 (VCC), U11.31 (~WE), U11.32 (VCC), U12.14 (VCC), U35.2, U35.5, U35.10, U35.14 (VCC), U36.7 (VCC); also elsewhere on the board
/ALU/BUS0: U8.3 (D0); also elsewhere on the board
/ALU/BUS1: U8.4 (D1); also elsewhere on the board
/ALU/BUS2: U8.7 (D2); also elsewhere on the board
/ALU/BUS3: U8.8 (D3); also elsewhere on the board
/ALU/BUS4: U8.13 (D4); also elsewhere on the board
/ALU/BUS5: U8.14 (D5); also elsewhere on the board
/ALU/C_FLAG: U6.5 (D2); also elsewhere on the board
/ALU/EC: U11.14 (I/O1); also elsewhere on the board
/ALU/ES: U11.15 (I/O2); also elsewhere on the board
/ALU/N_FLAG: U6.4 (D1); also elsewhere on the board
/ALU/ZH_FLAG: U35.13; also elsewhere on the board
/ALU/ZL_FLAG: U35.12; also elsewhere on the board
/ALU/~EO: U11.13 (I/O0); also elsewhere on the board
/Control Logic/CE: U9.21 (I/O7); also elsewhere on the board
/Control Logic/CPU_OSC: D100.1 (K), U12.5, U35.1, U36.15 (PB1)
/Control Logic/Flag0: D71.2 (A), U6.14 (Q0), U7.23 (A10), U9.23 (A10), U11.23 (A10)
/Control Logic/Flag1: D70.2 (A), U6.13 (Q1), U7.25 (A11), U9.25 (A11), U11.25 (A11)
/Control Logic/Flag2: D69.2 (A), U6.12 (Q2), U7.4 (A12), U9.4 (A12), U11.4 (A12)
/Control Logic/Flag3: D68.2 (A), U6.11 (Q3), U7.28 (A13), U9.28 (A13), U11.28 (A13)
/Control Logic/Inst0: D63.2 (A), U7.8 (A4), U8.2 (Q0), U9.8 (A4), U11.8 (A4)
/Control Logic/Inst1: D62.2 (A), U7.7 (A5), U8.5 (Q1), U9.7 (A5), U11.7 (A5)
/Control Logic/Inst2: D61.2 (A), U7.6 (A6), U8.6 (Q2), U9.6 (A6), U11.6 (A6)
/Control Logic/Inst3: D60.2 (A), U7.5 (A7), U8.9 (Q3), U9.5 (A7), U11.5 (A7)
/Control Logic/Inst4: D64.2 (A), U7.27 (A8), U8.12 (Q4), U9.27 (A8), U11.27 (A8)
/Control Logic/Inst5: D67.2 (A), U7.26 (A9), U8.15 (Q5), U9.26 (A9), U11.26 (A9)
/Control Logic/ME: U7.13 (I/O0); also elsewhere on the board
/Control Logic/Step0: D75.2 (A), U7.12 (A0), U9.12 (A0), U10.14 (Q0), U11.12 (A0)
/Control Logic/Step1: D74.2 (A), U7.11 (A1), U9.11 (A1), U10.13 (Q1), U11.11 (A1)
/Control Logic/Step2: D73.2 (A), U7.10 (A2), U9.10 (A2), U10.12 (Q2), U11.10 (A2)
/Control Logic/Step3: D72.2 (A), U7.9 (A3), U9.9 (A3), U10.11 (Q3), U11.9 (A3)
/Control Logic/~AI: U11.19 (I/O5); also elsewhere on the board
/Control Logic/~AO: U11.20 (I/O6); also elsewhere on the board
/Control Logic/~BI: U11.17 (I/O3); also elsewhere on the board
/Control Logic/~BO: U11.18 (I/O4); also elsewhere on the board
/Control Logic/~CIH: U9.18 (I/O4); also elsewhere on the board
/Control Logic/~CIL: U9.17 (I/O3); also elsewhere on the board
/Control Logic/~COH: U9.20 (I/O6); also elsewhere on the board
/Control Logic/~COL: U9.19 (I/O5); also elsewhere on the board
/Control Logic/~FI: D89.1 (K), U6.9 (~PE), U9.14 (I/O1)
/Control Logic/~IC: D91.1 (K), U9.15 (I/O2), U10.9 (~PE)
/Control Logic/~II: D90.1 (K), U8.1 (EN), U9.13 (I/O0)
/Control Logic/~MIH: U7.15 (I/O2); also elsewhere on the board
/Control Logic/~MIL: U7.14 (I/O1); also elsewhere on the board
/Control Logic/~RI_PLS: U12.8; also elsewhere on the board
/Control Logic/~RI: D82.1 (K), U7.20 (I/O6), U12.9
/Control Logic/~RO: U7.21 (I/O7); also elsewhere on the board
/Control Logic/~R_FLAG: U6.6 (D3); also elsewhere on the board
/Control Logic/~TI_PLS: U12.11; also elsewhere on the board
/Control Logic/~TI: D87.1 (K), U7.17 (I/O3), U12.12
/Control Logic/~TO: U7.18 (I/O4); also elsewhere on the board
/Control Logic/~TR_PLS: U12.3; also elsewhere on the board
/Control Logic/~TR: U7.19 (I/O5), U12.1
/Control Logic/~Z_FLAG: U6.3 (D0), U35.11
CLK: R2.2, U6.2 (CP), U10.2 (CP), U12.2, U12.4, U35.8; also elsewhere on the board
GND: C1.1, C2.1, R4.2, R5.2, R6.2, RN9.1 (common), RN10.1 (common), RN11.1 (common), SW1.2, SW2.1, SW3.1, U6.7 (CEP), U6.8 (GND), U6.10 (CET), U7.1 (A18), U7.2 (A16), U7.3 (A15), U7.16 (GND), U7.22 (~CE), U7.24 (~OE), U7.29 (A14), U7.30 (A17), U8.10 (GND), U8.17 (D6), U8.18 (D7), U9.1 (A18), U9.2 (A16), U9.3 (A15), U9.16 (GND), U9.22 (~CE), U9.24 (~OE), U9.29 (A14), U9.30 (A17), U10.3 (D0), U10.4 (D1), U10.5 (D2), U10.6 (D3), U10.8 (GND), U11.1 (A18), U11.2 (A16), U11.3 (A15), U11.16 (GND), U11.22 (~CE), U11.24 (~OE), U11.29 (A14), U11.30 (A17), U12.7 (GND), U35.7 (GND), U36.8 (GND), U36.22 (GND); also elsewhere on the board
unnamed: D1.2 (A), U36.25 (PC2)
unnamed: D1.1 (K), R4.1
unnamed: D2.2 (A), U36.24 (PC1)
unnamed: D2.1 (K), R5.1
unnamed: D3.2 (A), U36.23 (PC0)
unnamed: D3.1 (K), R6.1
unnamed: D60.1 (K), RN9.6 (R5)
unnamed: D61.1 (K), RN9.7 (R6)
unnamed: D62.1 (K), RN9.8 (R7)
unnamed: D63.1 (K), RN9.9 (R8)
unnamed: D64.1 (K), RN9.5 (R4)
unnamed: D67.1 (K), RN9.4 (R3)
unnamed: D68.1 (K), RN11.6 (R5)
unnamed: D69.1 (K), RN11.7 (R6)
unnamed: D70.1 (K), RN11.8 (R7)
unnamed: D71.1 (K), RN11.9 (R8)
unnamed: D72.1 (K), RN10.6 (R5)
unnamed: D73.1 (K), RN10.7 (R6)
unnamed: D74.1 (K), RN10.8 (R7)
unnamed: D75.1 (K), RN10.9 (R8)
unnamed: D82.2 (A), R15.1
unnamed: D87.2 (A), R20.1
unnamed: D89.2 (A), R22.1
unnamed: D90.2 (A), R23.1
unnamed: D91.2 (A), R24.1
unnamed: D100.2 (A), R33.1
unnamed: R2.1, U8.11 (CP)
unnamed: U35.3, U35.4
unnamed: U35.6, U35.9
unnamed: SW2.2, U36.14 (PB0)
unnamed: SW3.2, U36.16 (PB2)
unnamed: C1.2, U36.9 (XTAL1/PB6), Y1.1
unnamed: C2.2, U36.10 (XTAL2/PB7), Y1.2
unnamed: R3.2, U36.1 (~RESET/PC6)
UART_OSC: U36.17 (PB3); also elsewhere on the board
~PLS: U12.6, U12.10, U12.13; also elsewhere on the board
~RESET: R1.2, SW1.1, U6.1 (~MR), U10.1 (~MR); also elsewhere on the board

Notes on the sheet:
INSTRUCTION REGISTER
RESET (SC, FR, PC)
STEP COUNTER
FLAGS REGISTER
Use RC constant to synchronize IR outputs with FR/SC outputs.

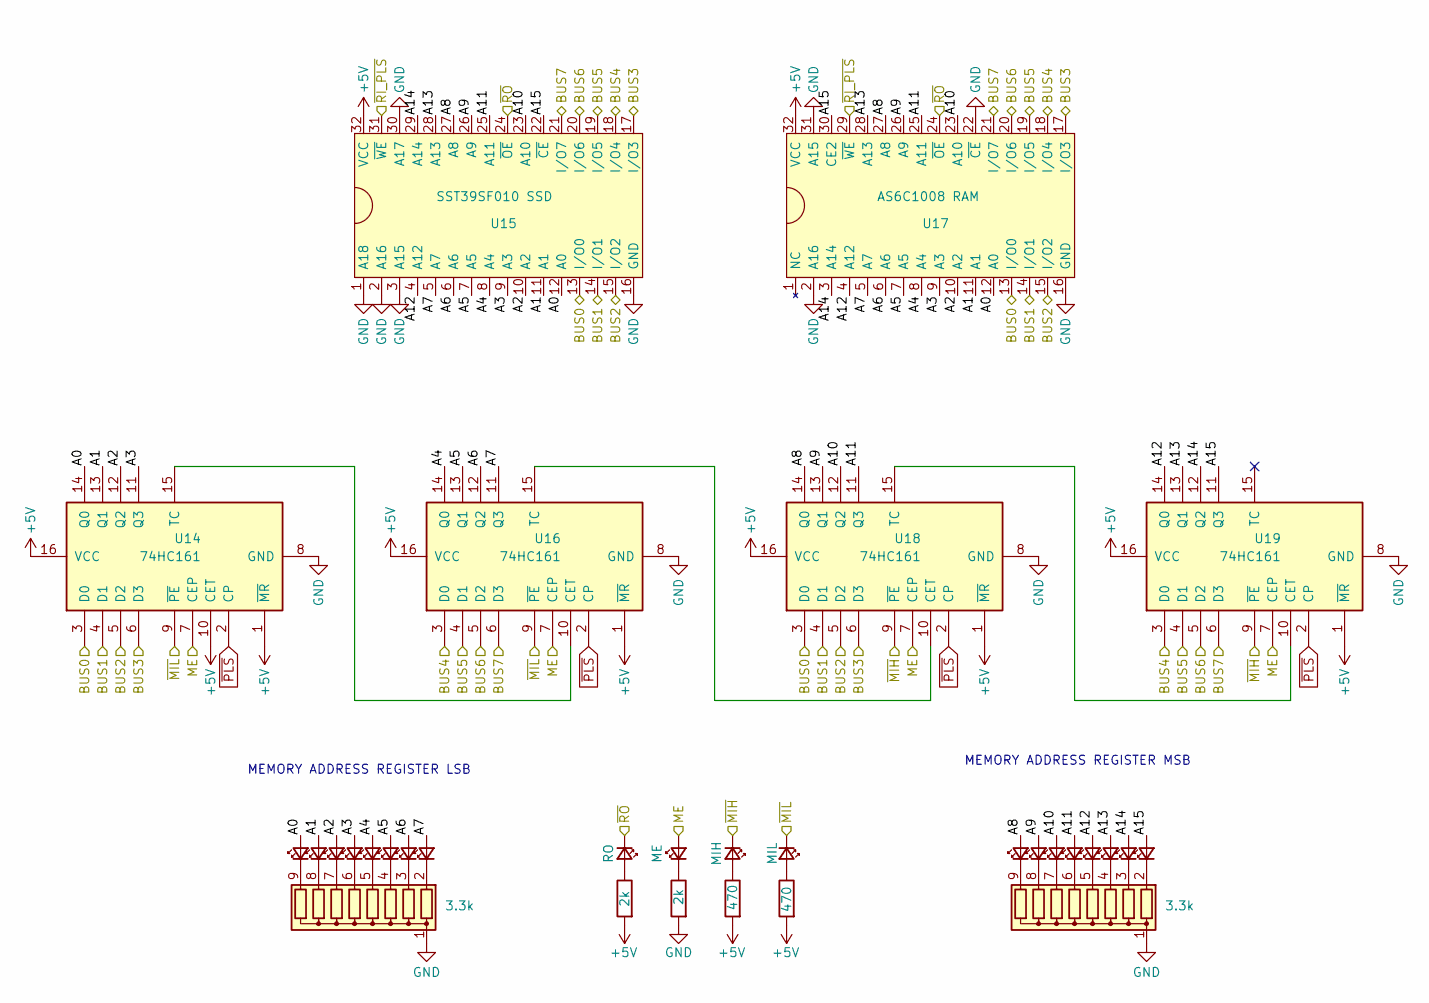
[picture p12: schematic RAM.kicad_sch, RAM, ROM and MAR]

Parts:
D4, D5, D6, D7, D8, D9, D10, D11, D12, D13, D14, D15, D16, D17, D18, D19: LED_Small; LED_D5.0mm
D85: MIL; LED_D5.0mm
D86: MIH; LED_D5.0mm
D88: ME; LED_D5.0mm
D99: RO; LED_D5.0mm
R18, R19: 470; R_Axial_DIN0207_L6.3mm_D2.5mm_P7.62mm_Horizontal
R21, R32: 2k; R_Axial_DIN0207_L6.3mm_D2.5mm_P7.62mm_Horizontal
RN2, RN3: 3.3k; R_Array_SIP9
U14, U16, U18, U19: 74HC161; DIP-16_W7.62mm
U15: SST39SF010 SSD; DIP-32_W15.24mm
U17: AS6C1008 RAM; DIP-32_W15.24mm

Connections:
+5V: R18.2, R19.2, R32.2, U14.1 (~MR), U14.10 (CET), U14.16 (VCC), U15.32 (VCC), U16.1 (~MR), U16.16 (VCC), U17.32 (VCC), U18.1 (~MR), U18.16 (VCC), U19.1 (~MR), U19.16 (VCC); also elsewhere on the board
/ALU/BUS0: U14.3 (D0), U15.13 (I/O0), U17.13 (I/O0), U18.3 (D0); also elsewhere on the board
/ALU/BUS1: U14.4 (D1), U15.14 (I/O1), U17.14 (I/O1), U18.4 (D1); also elsewhere on the board
/ALU/BUS2: U14.5 (D2), U15.15 (I/O2), U17.15 (I/O2), U18.5 (D2); also elsewhere on the board
/ALU/BUS3: U14.6 (D3), U15.17 (I/O3), U17.17 (I/O3), U18.6 (D3); also elsewhere on the board
/ALU/BUS4: U15.18 (I/O4), U16.3 (D0), U17.18 (I/O4), U19.3 (D0); also elsewhere on the board
/ALU/BUS5: U15.19 (I/O5), U16.4 (D1), U17.19 (I/O5), U19.4 (D1); also elsewhere on the board
/ALU/BUS6: U15.20 (I/O6), U16.5 (D2), U17.20 (I/O6), U19.5 (D2); also elsewhere on the board
/ALU/BUS7: U15.21 (I/O7), U16.6 (D3), U17.21 (I/O7), U19.6 (D3); also elsewhere on the board
/Control Logic/ME: D88.2 (A), U14.7 (CEP), U16.7 (CEP), U18.7 (CEP), U19.7 (CEP); also elsewhere on the board
/Control Logic/~MIH: D86.1 (K), U18.9 (~PE), U19.9 (~PE); also elsewhere on the board
/Control Logic/~MIL: D85.1 (K), U14.9 (~PE), U16.9 (~PE); also elsewhere on the board
/Control Logic/~RI_PLS: U15.31 (~WE), U17.29 (~WE); also elsewhere on the board
/Control Logic/~RO: D99.1 (K), U15.24 (~OE), U17.24 (~OE); also elsewhere on the board
/Memory/A0: D7.2 (A), U14.14 (Q0), U15.12 (A0), U17.12 (A0)
/Memory/A1: D6.2 (A), U14.13 (Q1), U15.11 (A1), U17.11 (A1)
/Memory/A2: D5.2 (A), U14.12 (Q2), U15.10 (A2), U17.10 (A2)
/Memory/A3: D4.2 (A), U14.11 (Q3), U15.9 (A3), U17.9 (A3)
/Memory/A4: D11.2 (A), U15.8 (A4), U16.14 (Q0), U17.8 (A4)
/Memory/A5: D10.2 (A), U15.7 (A5), U16.13 (Q1), U17.7 (A5)
/Memory/A6: D9.2 (A), U15.6 (A6), U16.12 (Q2), U17.6 (A6)
/Memory/A7: D8.2 (A), U15.5 (A7), U16.11 (Q3), U17.5 (A7)
/Memory/A8: D12.2 (A), U15.27 (A8), U17.27 (A8), U18.14 (Q0)
/Memory/A9: D13.2 (A), U15.26 (A9), U17.26 (A9), U18.13 (Q1)
/Memory/A10: D14.2 (A), U15.23 (A10), U17.23 (A10), U18.12 (Q2)
/Memory/A11: D15.2 (A), U15.25 (A11), U17.25 (A11), U18.11 (Q3)
/Memory/A12: D16.2 (A), U15.4 (A12), U17.4 (A12), U19.14 (Q0)
/Memory/A13: D17.2 (A), U15.28 (A13), U17.28 (A13), U19.13 (Q1)
/Memory/A14: D18.2 (A), U15.29 (A14), U17.3 (A14), U19.12 (Q2)
/Memory/A15: D19.2 (A), U15.22 (~CE), U17.30 (CE2), U19.11 (Q3)
GND: R21.2, RN2.1 (common), RN3.1 (common), U14.8 (GND), U15.1 (A18), U15.2 (A16), U15.3 (A15), U15.16 (GND), U15.30 (A17), U16.8 (GND), U17.2 (A16), U17.16 (GND), U17.22 (~CE), U17.31 (A15), U18.8 (GND), U19.8 (GND); also elsewhere on the board
unnamed: D4.1 (K), RN2.6 (R5)
unnamed: D5.1 (K), RN2.7 (R6)
unnamed: D6.1 (K), RN2.8 (R7)
unnamed: D7.1 (K), RN2.9 (R8)
unnamed: D8.1 (K), RN2.2 (R1)
unnamed: D9.1 (K), RN2.3 (R2)
unnamed: D10.1 (K), RN2.4 (R3)
unnamed: D11.1 (K), RN2.5 (R4)
unnamed: D12.1 (K), RN3.9 (R8)
unnamed: D13.1 (K), RN3.8 (R7)
unnamed: D14.1 (K), RN3.7 (R6)
unnamed: D15.1 (K), RN3.6 (R5)
unnamed: D16.1 (K), RN3.5 (R4)
unnamed: D17.1 (K), RN3.4 (R3)
unnamed: D18.1 (K), RN3.3 (R2)
unnamed: D19.1 (K), RN3.2 (R1)
unnamed: D85.2 (A), R18.1
unnamed: D86.2 (A), R19.1
unnamed: D88.1 (K), R21.1
unnamed: D99.2 (A), R32.1
unnamed: U14.15 (TC), U16.10 (CET)
unnamed: U16.15 (TC), U18.10 (CET)
unnamed: U18.15 (TC), U19.10 (CET)
~PLS: U14.2 (CP), U16.2 (CP), U18.2 (CP), U19.2 (CP); also elsewhere on the board

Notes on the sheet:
MEMORY ADDRESS REGISTER LSB
MEMORY ADDRESS REGISTER MSB

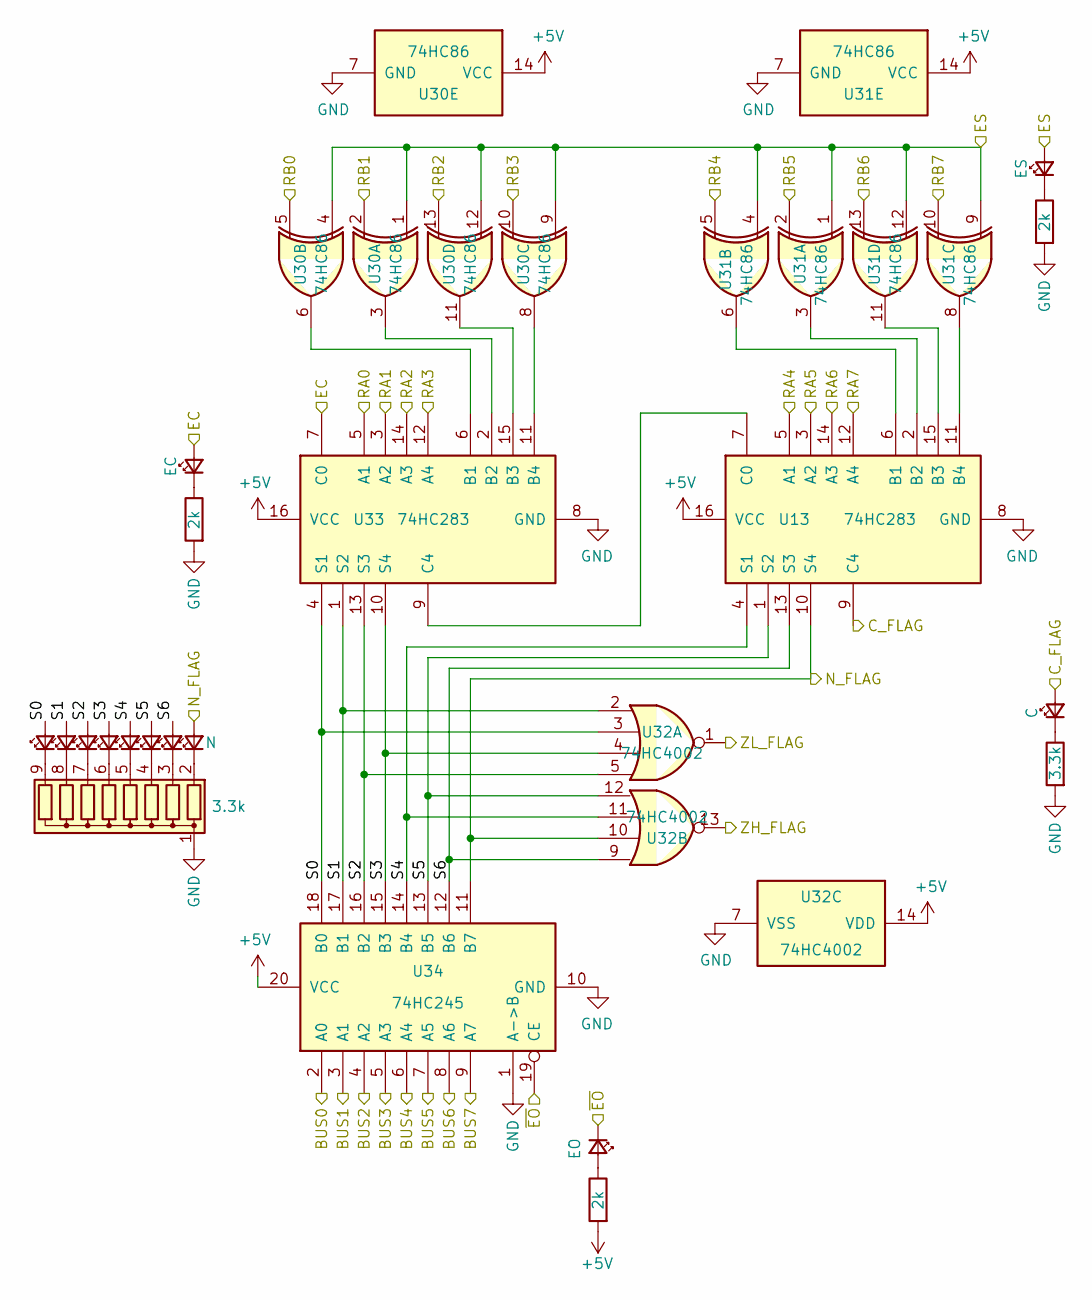
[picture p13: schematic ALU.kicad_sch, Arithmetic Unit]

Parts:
D52, D53, D54, D55, D56, D57, D58: LED_Small; LED_D5.0mm
D59: N; LED_D5.0mm
D78: EO; LED_D5.0mm
D93: EC; LED_D5.0mm
D94: ES; LED_D5.0mm
D95: C; LED_D5.0mm
R11, R26, R27: 2k; R_Axial_DIN0207_L6.3mm_D2.5mm_P7.62mm_Horizontal
R28: 3.3k; R_Axial_DIN0207_L6.3mm_D2.5mm_P7.62mm_Horizontal
RN8: 3.3k; R_Array_SIP9
U13, U33: 74HC283; DIP-16_W7.62mm
U30, U31: 74HC86; DIP-14_W7.62mm
U32: 74HC4002; DIP-14_W7.62mm
U34: 74HC245; DIP-20_W7.62mm

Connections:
+5V: R11.2, U13.16 (VCC), U30.14 (VCC), U31.14 (VCC), U32.14 (VDD), U33.16 (VCC), U34.20 (VCC); also elsewhere on the board
/ALU/BUS0: U34.2 (A0); also elsewhere on the board
/ALU/BUS1: U34.3 (A1); also elsewhere on the board
/ALU/BUS2: U34.4 (A2); also elsewhere on the board
/ALU/BUS3: U34.5 (A3); also elsewhere on the board
/ALU/BUS4: U34.6 (A4); also elsewhere on the board
/ALU/BUS5: U34.7 (A5); also elsewhere on the board
/ALU/BUS6: U34.8 (A6); also elsewhere on the board
/ALU/BUS7: U34.9 (A7); also elsewhere on the board
/ALU/C_FLAG: D95.2 (A), U13.9 (C4); also elsewhere on the board
/ALU/EC: D93.2 (A), U33.7 (C0); also elsewhere on the board
/ALU/ES: D94.2 (A), U30.1, U30.4, U30.9, U30.12, U31.1, U31.4, U31.9, U31.12; also elsewhere on the board
/ALU/N_FLAG: D59.2 (A), U13.10 (S4), U32.10, U34.11 (B7); also elsewhere on the board
/ALU/RA0: U33.5 (A1); also elsewhere on the board
/ALU/RA1: U33.3 (A2); also elsewhere on the board
/ALU/RA2: U33.14 (A3); also elsewhere on the board
/ALU/RA3: U33.12 (A4); also elsewhere on the board
/ALU/RA4: U13.5 (A1); also elsewhere on the board
/ALU/RA5: U13.3 (A2); also elsewhere on the board
/ALU/RA6: U13.14 (A3); also elsewhere on the board
/ALU/RA7: U13.12 (A4); also elsewhere on the board
/ALU/RB0: U30.5; also elsewhere on the board
/ALU/RB1: U30.2; also elsewhere on the board
/ALU/RB2: U30.13; also elsewhere on the board
/ALU/RB3: U30.10; also elsewhere on the board
/ALU/RB4: U31.5; also elsewhere on the board
/ALU/RB5: U31.2; also elsewhere on the board
/ALU/RB6: U31.13; also elsewhere on the board
/ALU/RB7: U31.10; also elsewhere on the board
/ALU/S0: D52.2 (A), U32.3, U33.4 (S1), U34.18 (B0)
/ALU/S1: D53.2 (A), U32.2, U33.1 (S2), U34.17 (B1)
/ALU/S2: D54.2 (A), U32.5, U33.13 (S3), U34.16 (B2)
/ALU/S3: D55.2 (A), U32.4, U33.10 (S4), U34.15 (B3)
/ALU/S4: D56.2 (A), U13.4 (S1), U32.11, U34.14 (B4)
/ALU/S5: D57.2 (A), U13.1 (S2), U32.12, U34.13 (B5)
/ALU/S6: D58.2 (A), U13.13 (S3), U32.9, U34.12 (B6)
/ALU/ZH_FLAG: U32.13; also elsewhere on the board
/ALU/ZL_FLAG: U32.1; also elsewhere on the board
/ALU/~EO: D78.1 (K), U34.19 (CE); also elsewhere on the board
GND: R26.2, R27.2, R28.2, RN8.1 (common), U13.8 (GND), U30.7 (GND), U31.7 (GND), U32.7 (VSS), U33.8 (GND), U34.1 (A->B), U34.10 (GND); also elsewhere on the board
unnamed: D52.1 (K), RN8.9 (R8)
unnamed: D53.1 (K), RN8.8 (R7)
unnamed: D54.1 (K), RN8.7 (R6)
unnamed: D55.1 (K), RN8.6 (R5)
unnamed: D56.1 (K), RN8.5 (R4)
unnamed: D57.1 (K), RN8.4 (R3)
unnamed: D58.1 (K), RN8.3 (R2)
unnamed: D59.1 (K), RN8.2 (R1)
unnamed: D78.2 (A), R11.1
unnamed: D93.1 (K), R26.1
unnamed: D94.1 (K), R27.1
unnamed: D95.1 (K), R28.1
unnamed: U13.6 (B1), U31.6
unnamed: U13.2 (B2), U31.3
unnamed: U13.15 (B3), U31.11
unnamed: U13.11 (B4), U31.8
unnamed: U13.7 (C0), U33.9 (C4)
unnamed: U30.6, U33.6 (B1)
unnamed: U30.3, U33.2 (B2)
unnamed: U30.11, U33.15 (B3)
unnamed: U30.8, U33.11 (B4)

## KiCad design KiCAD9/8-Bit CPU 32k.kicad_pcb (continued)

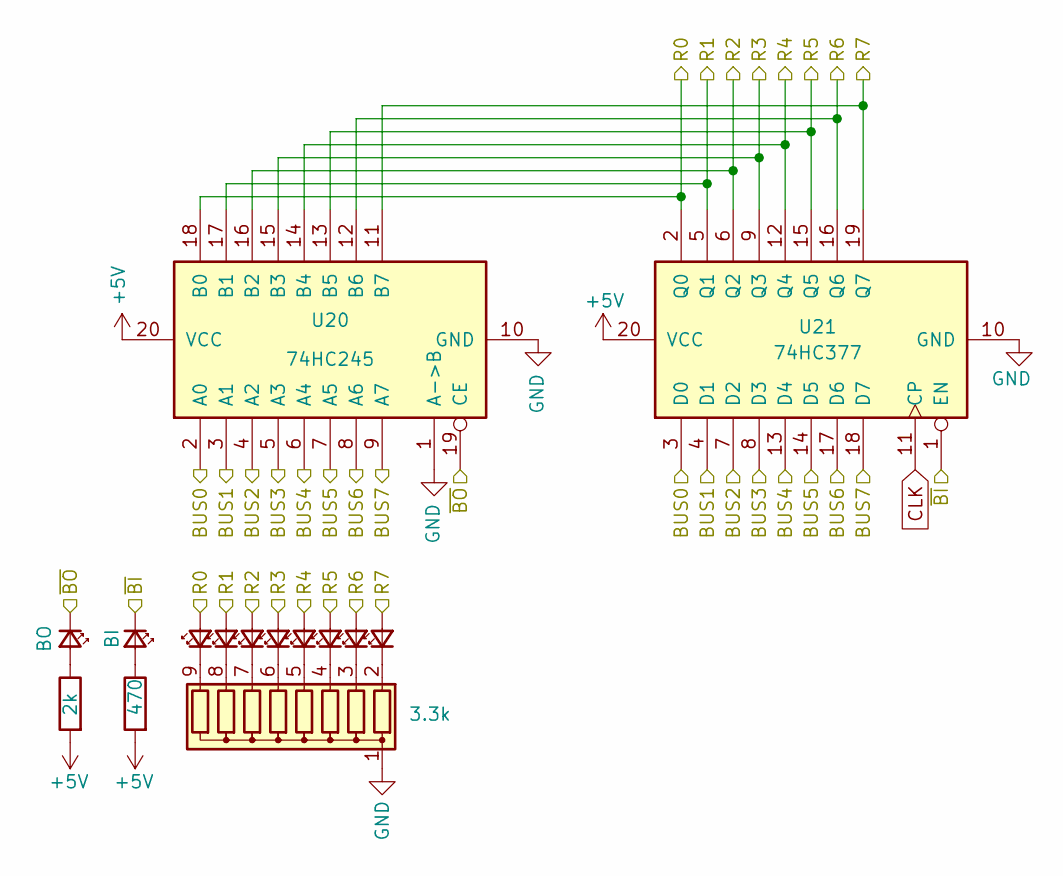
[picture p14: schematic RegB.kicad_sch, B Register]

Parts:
D44, D45, D46, D47, D48, D49, D50, D51: LED_Small; LED_D5.0mm
D76: BI; LED_D5.0mm
D77: BO; LED_D5.0mm
R9: 470; R_Axial_DIN0207_L6.3mm_D2.5mm_P7.62mm_Horizontal
R10: 2k; R_Axial_DIN0207_L6.3mm_D2.5mm_P7.62mm_Horizontal
RN7: 3.3k; R_Array_SIP9
U20: 74HC245; DIP-20_W7.62mm
U21: 74HC377; DIP-20_W7.62mm

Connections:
+5V: R9.2, R10.2, U20.20 (VCC), U21.20 (VCC); also elsewhere on the board
/ALU/BUS0: U20.2 (A0), U21.3 (D0); also elsewhere on the board
/ALU/BUS1: U20.3 (A1), U21.4 (D1); also elsewhere on the board
/ALU/BUS2: U20.4 (A2), U21.7 (D2); also elsewhere on the board
/ALU/BUS3: U20.5 (A3), U21.8 (D3); also elsewhere on the board
/ALU/BUS4: U20.6 (A4), U21.13 (D4); also elsewhere on the board
/ALU/BUS5: U20.7 (A5), U21.14 (D5); also elsewhere on the board
/ALU/BUS6: U20.8 (A6), U21.17 (D6); also elsewhere on the board
/ALU/BUS7: U20.9 (A7), U21.18 (D7); also elsewhere on the board
/ALU/RB0: D44.2 (A), U20.18 (B0), U21.2 (Q0); also elsewhere on the board
/ALU/RB1: D45.2 (A), U20.17 (B1), U21.5 (Q1); also elsewhere on the board
/ALU/RB2: D46.2 (A), U20.16 (B2), U21.6 (Q2); also elsewhere on the board
/ALU/RB3: D47.2 (A), U20.15 (B3), U21.9 (Q3); also elsewhere on the board
/ALU/RB4: D48.2 (A), U20.14 (B4), U21.12 (Q4); also elsewhere on the board
/ALU/RB5: D49.2 (A), U20.13 (B5), U21.15 (Q5); also elsewhere on the board
/ALU/RB6: D50.2 (A), U20.12 (B6), U21.16 (Q6); also elsewhere on the board
/ALU/RB7: D51.2 (A), U20.11 (B7), U21.19 (Q7); also elsewhere on the board
/Control Logic/~BI: D76.1 (K), U21.1 (EN); also elsewhere on the board
/Control Logic/~BO: D77.1 (K), U20.19 (CE); also elsewhere on the board
CLK: U21.11 (CP); also elsewhere on the board
GND: RN7.1 (common), U20.1 (A->B), U20.10 (GND), U21.10 (GND); also elsewhere on the board
unnamed: D44.1 (K), RN7.9 (R8)
unnamed: D45.1 (K), RN7.8 (R7)
unnamed: D46.1 (K), RN7.7 (R6)
unnamed: D47.1 (K), RN7.6 (R5)
unnamed: D48.1 (K), RN7.5 (R4)
unnamed: D49.1 (K), RN7.4 (R3)
unnamed: D50.1 (K), RN7.3 (R2)
unnamed: D51.1 (K), RN7.2 (R1)
unnamed: D76.2 (A), R9.1
unnamed: D77.2 (A), R10.1

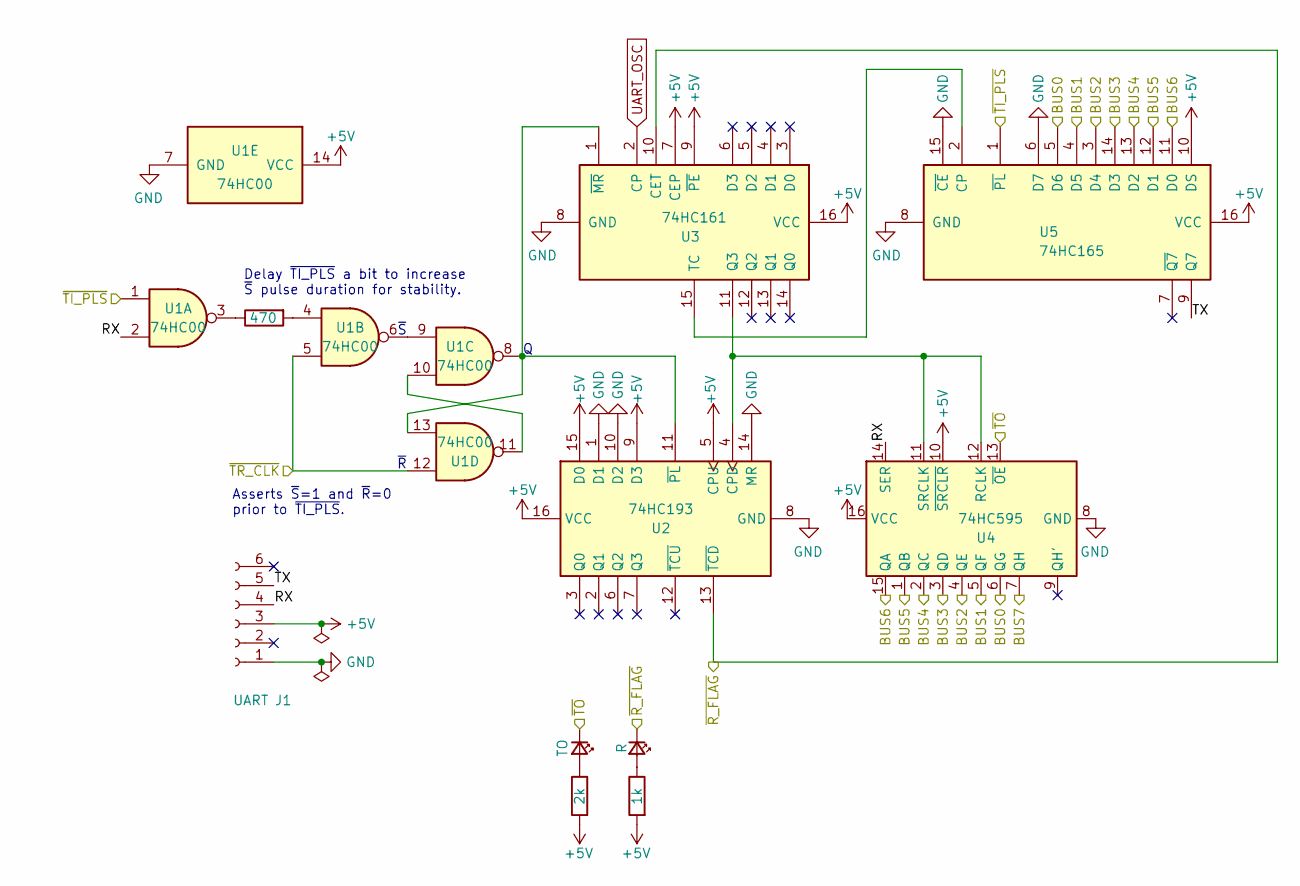
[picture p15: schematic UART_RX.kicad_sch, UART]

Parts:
D80: TO; LED_D5.0mm
D97: R; LED_D5.0mm
J1: UART; PinSocket_1x06_P2.54mm_Vertical
R13: 2k; R_Axial_DIN0207_L6.3mm_D2.5mm_P7.62mm_Horizontal
R29: 470; R_Axial_DIN0207_L6.3mm_D2.5mm_P7.62mm_Horizontal
R30: 1k; R_Axial_DIN0207_L6.3mm_D2.5mm_P7.62mm_Horizontal
U1: 74HC00; DIP-14_W7.62mm
U2: 74HC193; DIP-16_W7.62mm
U3: 74HC161; DIP-16_W7.62mm
U4: 74HC595; DIP-16_W7.62mm
U5: 74HC165; DIP-16_W7.62mm

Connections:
+5V: J1.3, R13.2, R30.2, U1.14 (VCC), U2.5 (CPU), U2.9 (D3), U2.15 (D0), U2.16 (VCC), U3.7 (CEP), U3.9 (~PE), U3.16 (VCC), U4.10 (~SRCLR), U4.16 (VCC), U5.10 (DS), U5.16 (VCC); also elsewhere on the board
/ALU/BUS0: U4.6 (QG), U5.5 (D6); also elsewhere on the board
/ALU/BUS1: U4.5 (QF), U5.4 (D5); also elsewhere on the board
/ALU/BUS2: U4.4 (QE), U5.3 (D4); also elsewhere on the board
/ALU/BUS3: U4.3 (QD), U5.14 (D3); also elsewhere on the board
/ALU/BUS4: U4.2 (QC), U5.13 (D2); also elsewhere on the board
/ALU/BUS5: U4.1 (QB), U5.12 (D1); also elsewhere on the board
/ALU/BUS6: U4.15 (QA), U5.11 (D0); also elsewhere on the board
/ALU/BUS7: U4.7 (QH); also elsewhere on the board
/Control Logic/~R_FLAG: D97.1 (K), U2.13 (~TCD), U3.10 (CET); also elsewhere on the board
/Control Logic/~TI_PLS: U1.1, U5.1 (~PL); also elsewhere on the board
/Control Logic/~TO: D80.1 (K), U4.13 (~OE); also elsewhere on the board
/Control Logic/~TR_PLS: U1.5, U1.12; also elsewhere on the board
/UART/RX: J1.4, U1.2, U4.14 (SER)
/UART/TX: J1.5, U5.9 (Q7)
GND: J1.1, U1.7 (GND), U2.1 (D1), U2.8 (GND), U2.10 (D2), U2.14 (MR), U3.8 (GND), U4.8 (GND), U5.6 (D7), U5.8 (GND), U5.15 (~CE); also elsewhere on the board
unnamed: D80.2 (A), R13.1
unnamed: D97.2 (A), R30.1
unnamed: R29.1, U1.3
unnamed: R29.2, U1.4
unnamed: U1.6, U1.9
unnamed: U1.10, U1.11
unnamed: U2.4 (CPD), U3.11 (Q3), U4.11 (SRCLK), U4.12 (RCLK)
unnamed: U1.8, U1.13, U2.11 (~PL), U3.1 (~MR)
unnamed: U3.15 (TC), U5.2 (CP)
UART_OSC: U3.2 (CP); also elsewhere on the board

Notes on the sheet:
Delay ~{TI_PLS} a bit to increase ~{S} pulse duration for stability.
Asserts ~{S}=1 and ~{R}=0 prior to ~{TI_PLS}.
~{S}
~{R}

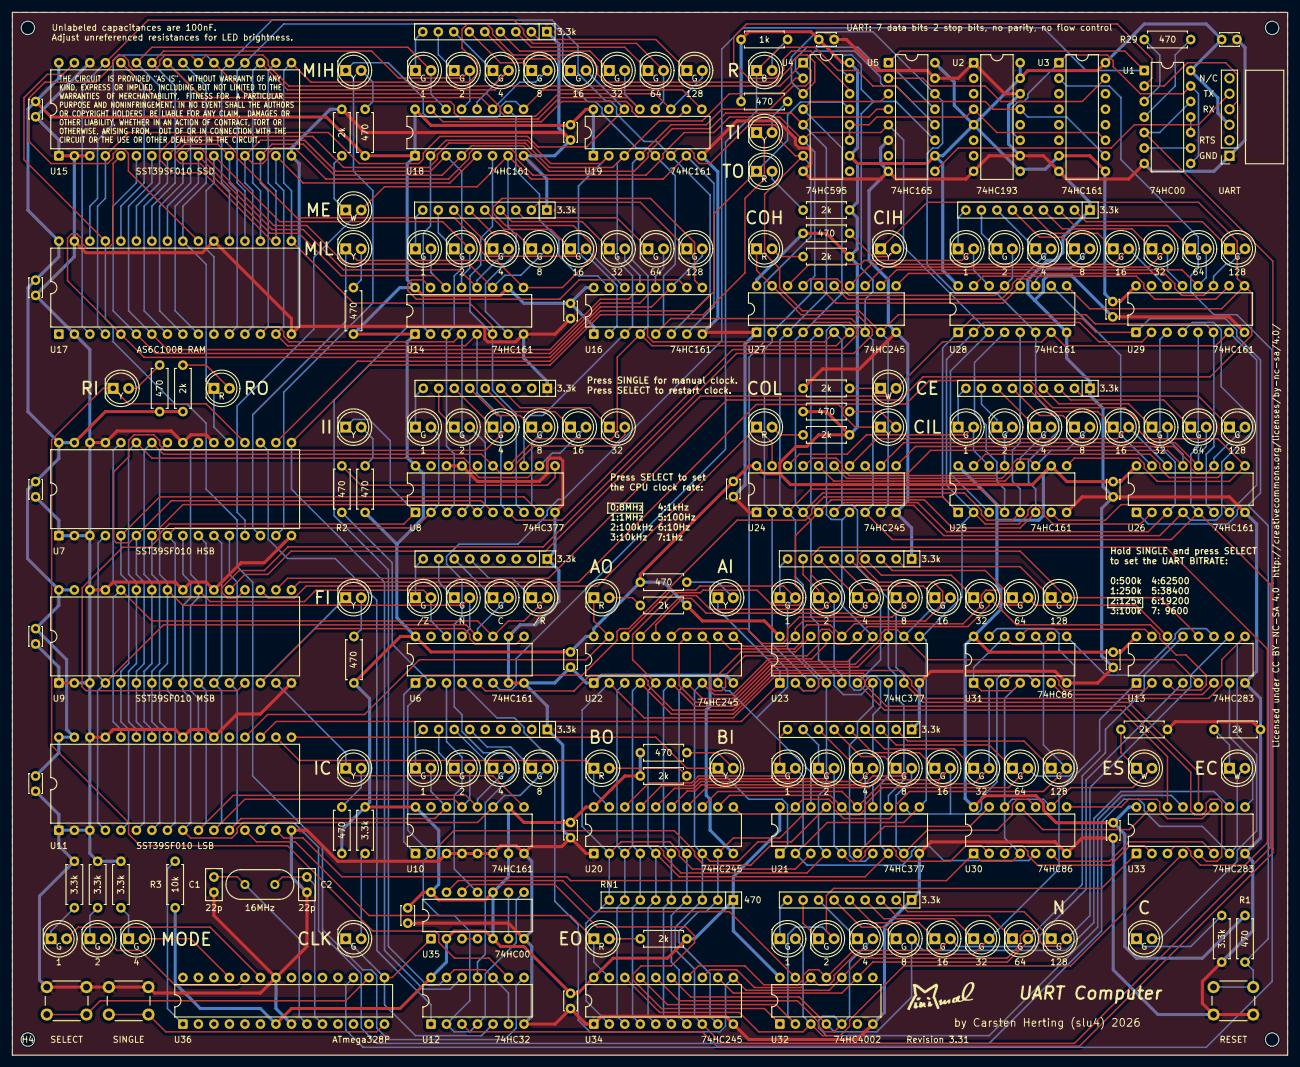
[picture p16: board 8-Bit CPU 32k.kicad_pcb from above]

Board: 2 copper layers, 208.9 x 170.8 mm, 206 parts (0 on the bottom side), 249 nets.

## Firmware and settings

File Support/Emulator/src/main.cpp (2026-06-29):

// *******************************************************************************
// ***** Minimal UART Computer 3 Emulator by Carsten Herting - Jun 29th 2026 *****
// *******************************************************************************
// See licensing information at the end of this file.

// sudo apt install picocom
// picocom -b 125000 --databits 7 --parity n --stopbits 2 --flow n --imap lfcrlf --omap crlf /dev/ttyUSB0
// type 'receive' and upload file from another terminal: ./asm.exe mandel.asm | ./send.sh

#include "asm.h"

#include <iostream> // console output
#include <iomanip> // for std::setfill, std::hex,, std::dec
#include <fstream> // file input
#include <cstdint>
#include <cstring>
#include <string>
#include <stdexcept>
#include <memory> // smart pointers
#include <vector> // dynamic arrays
#include <deque>
#include <queue>
#include <thread>
#include <algorithm>
#include <utility> // for exchange
#include <unordered_map> // for shader uniform location cache

#include <glad/glad.h> // include OpenGL-Extension-Loader before GLFW
#include <GLFW/glfw3.h> // GLFW: GLFW_VERSION_MAJOR wird definiert -> nimmt Einfluss auf main()
#include <glm/glm.hpp> // OpenGL Math Header Library
#include <glm/gtc/type_ptr.hpp> // für glm::value_ptr

#undef TERMINAL_TO_FILE

//                          <------><------><------>
#define CTRL_INVERT_MASK  0b111111100111111111111001 // 0: control signal is active HIGH, 1: control signal is active LOW

#define FF                0b000000000000000000000000 // passive bus 0xff

#define EO                0b000000000000000000000001 // LSB
#define EC                0b000000000000000000000010
#define ES                0b000000000000000000000100
#define BI                0b000000000000000000001000
#define BO                0b000000000000000000010000
#define AI                0b000000000000000000100000
#define AO                0b000000000000000001000000
#define NN                0b000000000000000010000000 // unused
#define II                0b000000000000000100000000 // MSB
#define FI                0b000000000000001000000000
#define IC                0b000000000000010000000000
#define CIL               0b000000000000100000000000
#define CIH               0b000000000001000000000000
#define COL               0b000000000010000000000000
#define COH               0b000000000100000000000000
#define CE                0b000000001000000000000000
#define ME                0b000000010000000000000000 // HSB
#define MIL               0b000000100000000000000000
#define MIH               0b000001000000000000000000
#define TI                0b000010000000000000000000
#define TO                0b000100000000000000000000
#define TR                0b001000000000000000000000
#define RI                0b010000000000000000000000
#define RO                0b100000000000000000000000

// flag lines set by ALU and read by flags-Register as "bus" input
#define FLAG_Z						0b0001									   // ~zero
#define FLAG_N						0b0010									   // negative
#define FLAG_C						0b0100									   // carry
#define FLAG_R						0b1000									   // ~data ready

#define TARGET_MENU       0
#define TARGET_SERIAL     1

enum COMPSTATE {RUN, HALT, SINGLESTEP, NEXTINST};
uint32_t gKeyTarget {TARGET_MENU};									 // defines the current keyboard input mode, used by the keyboard callback function
bool gFlashLoaded {false};
std::string gSerialInput;														 // the global strings receive input from the keyboard callback function
std::string gMenuInput;

extern "C" const char _binary_shader_glsl_start, _binary_shader_glsl_end; // linked binary resource symbols
extern "C" const char _binary_charset_bin_start, _binary_charset_bin_end;

class Shader
{
public:
  Shader(const char* start, const char* end) // takes pointer to embedded resource data or an identifier "id_..."
  {
    if (!start || !end || start >= end) throw std::runtime_error("Invalid shader source range provided.");
    std::string_view fullShaderCode(start, end-start); // this doesn't copy the string, very lightweight!
    std::string_view vertexShaderCode = ExtractShaderCode(fullShaderCode, "SHADER VERTEX");
    if (vertexShaderCode.empty()) throw std::runtime_error("Vertex shader code section is empty or missing.");
    std::string_view fragmentShaderCode = ExtractShaderCode(fullShaderCode, "SHADER FRAGMENT");
    if (fragmentShaderCode.empty()) throw std::runtime_error("Fragment shader code section is empty or missing.");
    GLuint vshaderid = CompileShader(GL_VERTEX_SHADER, vertexShaderCode);
    if (!vshaderid) throw std::runtime_error("Vertex Shader Compilation Error:\n" + mInfoLog);
    GLuint fshaderid = CompileShader(GL_FRAGMENT_SHADER, fragmentShaderCode);
    if (!fshaderid)
    {
      glDeleteShader(vshaderid);
      throw std::runtime_error("Fragment Shader Compilation Error:\n" + mInfoLog);
    }
    mProgID = LinkProgramDeleteShaders(vshaderid, fshaderid);
    if (!mProgID) throw std::runtime_error("Shader Linking Error\n" + mInfoLog);
  }
  ~Shader() noexcept { if (mProgID) glDeleteProgram(mProgID); mProgID=0; }
  Shader(const Shader& other) = delete; // no shallow copy for elements with allocated resources!
  Shader& operator=(const Shader& other) = delete;
  Shader(Shader&&) = delete;
  Shader& operator=(Shader&&) = delete;
  void Bind() const { glUseProgram(mProgID); }
  static void Unbind() { glUseProgram(0); } // Note: This is a static method as it affects global OpenGL state.
  template<typename T> void SetUniform(std::string_view name, const T& value); // using a template for different datatypes
private:
  std::string_view ExtractShaderCode(std::string_view code, const std::string& marker)
  {
    size_t startPos = code.find(marker);
    if (startPos == std::string_view::npos) throw std::runtime_error(marker + " section not found");
    startPos += marker.size();
    size_t endPos = code.find("SHADER END", startPos);
    if (endPos == std::string_view::npos) throw std::runtime_error(marker + " end marker not found");
    return code.substr(startPos, endPos - startPos);
  }
  GLuint CompileShader(GLenum type, std::string_view code)
  {
    mInfoLog.clear();
    
    GLuint shaderid = glCreateShader(type);
    if (!shaderid) { mInfoLog = "glCreateShader failed\n"; return 0; }

    const GLchar* shaderSrc = code.data();
    GLint shaderLen = static_cast<GLint>(code.size());
    glShaderSource(shaderid, 1, &shaderSrc, &shaderLen);
    glCompileShader(shaderid);
    GLint status; // Container für shader compiler status
    glGetShaderiv(shaderid, GL_COMPILE_STATUS, &status);
    if (status == GL_FALSE)
    {
      GLint len; glGetShaderiv(shaderid, GL_INFO_LOG_LENGTH, &len); // includes the '\0'
      if (len > 1)
      {
        mInfoLog.resize(static_cast<std::size_t>(len));
        glGetShaderInfoLog(shaderid, mInfoLog.size(), nullptr, mInfoLog.data());
        mInfoLog.pop_back(); // drop '\0'
      }
      glDeleteShader(shaderid); // free allocated resources
      return 0;
    }
    return shaderid;
  }
  GLuint LinkProgramDeleteShaders(GLuint vertexshaderid, GLuint fragmentshaderid)
  {
    mInfoLog.clear();

    GLuint progid = glCreateProgram(); // VS + FS = ShaderProg
    if (!progid) { mInfoLog = "glCreateProgram failed\n"; return 0; }

    glAttachShader(progid, vertexshaderid);
    glAttachShader(progid, fragmentshaderid);
    glLinkProgram(progid); // now the attached ShaderObjects are no longer needed and should be detached and than deleted.
    glDetachShader(progid, vertexshaderid); // cleanup
    glDetachShader(progid, fragmentshaderid);
    glDeleteShader(vertexshaderid); // mark for deletion (they are only really deleted after detachment!)
    glDeleteShader(fragmentshaderid); // undoes the effect of glCreateShader()

    GLint status; // Container für shader compiler status
    glGetProgramiv(progid, GL_LINK_STATUS, &status); // Status des Programms abfragen
    if (status == GL_FALSE)
    {
      GLint len; glGetProgramiv(progid, GL_INFO_LOG_LENGTH, &len); // includes the '\0'
      if (len > 1)
      {
        mInfoLog.resize(static_cast<std::size_t>(len));
        glGetProgramInfoLog(progid, mInfoLog.size(), nullptr, mInfoLog.data());
        mInfoLog.pop_back(); // drop '\0'
      }
      glDeleteProgram(progid);
      return 0;
    }
    return progid;
  }
  int GetUniformLocation(std::string_view name) const
  {
    std::string nameStr = std::string(name);
    auto it = mUniLocCache.find(nameStr); if (it != mUniLocCache.end()) return it->second; // Found in cache

    int location = glGetUniformLocation(mProgID, nameStr.c_str()); // erfrage die Location der Variable zum shaderprog ID von der GPU
    if (location == -1) std::cerr << "Shader: Unknown uniform: " << name << std::endl;
    mUniLocCache[nameStr] = location; // speichere die location dieser Variable in der bufptr
    return location; // gib die location dann auch zurück
  }
  mutable std::unordered_map<std::string, int> mUniLocCache; // bereits erfragte Locations speichern
  GLuint mProgID {0};
  std::string mInfoLog; // common storage for info log (compiler error messages outliving helper functions)
};
template<> inline void Shader::SetUniform<int>(std::string_view name, const int& i) { glUniform1i(GetUniformLocation(name), i); }
template<> inline void Shader::SetUniform<glm::vec4>(std::string_view name, const glm::vec4& vec) { glUniform4f(GetUniformLocation(name), vec.x, vec.y, vec.z, vec.w); }
template<> inline void Shader::SetUniform<glm::mat4>(std::string_view name, const glm::mat4& mat) { glUniformMatrix4fv(GetUniformLocation(name), 1, GL_FALSE, glm::value_ptr(mat)); }

class Display
{
public:
  Display(int width, int height)
  : mWidth(width), mHeight(height), mVideoBuffer(width * height, 0), mVertices(6, glm::vec4(0))
  {
    glGenTextures(1, &mTexture);
    glActiveTexture(GL_TEXTURE0); // any texture-related operations (like glBindTexture) will now apply to texture unit 0 (default)

    glGenBuffers(1, &mVBO);
    glGenVertexArrays(1, &mVAO); // generate buffers
    glBindVertexArray(mVAO); // begin recording into VAO...
      glBindBuffer(GL_ARRAY_BUFFER, mVBO); // VAO bezieht die folgenden calls auf diesen VBO
      glBufferData(GL_ARRAY_BUFFER, mVertices.size() * sizeof(glm::vec4), mVertices.data(), GL_STATIC_DRAW);
      glVertexAttribPointer(0, 2, GL_FLOAT, GL_FALSE, sizeof(glm::vec4), (GLvoid *)(0 * sizeof(GLfloat)));
      glEnableVertexAttribArray(0); // VAO: schalte Attribut "0" ein
      glVertexAttribPointer(1, 2, GL_FLOAT, GL_FALSE, sizeof(glm::vec4), (GLvoid *)(2 * sizeof(GLfloat))); // VAO: Attribut "0": Size 4 floats pro Attribut
      glEnableVertexAttribArray(1);
    glBindVertexArray(0); // stop recording into VAO...
    glBindBuffer(GL_ARRAY_BUFFER, 0); // unbind the VBO (not recorded)

    float w = width; float h = height;
    mProjMatrix = glm::ortho(0.0f, w, h, 0.0f, -1.0f, 1.0f);

    mShader.Bind();
    mShader.SetUniform("proj", mProjMatrix);
    mShader.SetUniform("drawtexunit", 0); // tell the shader via uniform to sample the texture from unit GL_TEXTURE0

    mVertices[0] = glm::vec4(0.0f,  0.0f,   0.0f, 0.0f); // calculate canvas rect vertices (two triangles)
    mVertices[1] = glm::vec4(w,     0.0f,   1.0f, 0.0f);
    mVertices[2] = glm::vec4(w,     h,      1.0f, 1.0f);

    mVertices[3] = glm::vec4(0.0f,  0.0f,   0.0f, 0.0f);
    mVertices[4] = glm::vec4(w,     h,      1.0f, 1.0f);
    mVertices[5] = glm::vec4(0.0f,  h,      0.0f, 1.0f);

    glBindBuffer(GL_ARRAY_BUFFER, mVBO); // update vertex data
      glBufferSubData(GL_ARRAY_BUFFER, 0, mVertices.size() * sizeof(glm::vec4), mVertices.data());
    glBindBuffer(GL_ARRAY_BUFFER, 0);

    glBindTexture(GL_TEXTURE_2D, mTexture);	// all upcoming GL_TEXTURE_2D operations now have effect on only this texture object
      glTexImage2D(GL_TEXTURE_2D, 0, GL_RGBA8, width, height, 0, GL_RGBA, GL_UNSIGNED_BYTE, nullptr); // reserve texture memory on GPU
      glTexParameteri(GL_TEXTURE_2D, GL_TEXTURE_MIN_FILTER, GL_NEAREST);
      glTexParameteri(GL_TEXTURE_2D, GL_TEXTURE_MAG_FILTER, GL_NEAREST);
    glBindTexture(GL_TEXTURE_2D, 0);
  }
  ~Display()
  {
    if (mTexture) { glDeleteTextures(1, &mTexture); mTexture = 0; }
    if (mVAO) { glDeleteVertexArrays(1, &mVAO); mVAO = 0; } // vertex array in der GPU löschen
    if (mVBO) { glDeleteBuffers(1, &mVBO); mVBO = 0; } // vertex buffer in der GPU löschen
  }
  Display(const Display& other) = delete; // no shallow copy for elements with allocated resources!
  Display& operator=(const Display& other) = delete;
  Display(Display&&) = delete;
  Display& operator=(Display&&) = delete;
  uint32_t* GetVideoRAMPtr() { return mVideoBuffer.data(); }
  void SetTint(float r, float g, float b, float a) { mTint = glm::vec4(r, g, b, a); }
  void Clear() { memset(mVideoBuffer.data(), 0, mWidth*mHeight*sizeof(uint32_t)); }
  void Render()
  {
    glBindTexture(GL_TEXTURE_2D, mTexture);	// All upcoming GL_TEXTURE_2D operations now have effect on only this texture object
    glTexSubImage2D(GL_TEXTURE_2D, 0, 0, 0, mWidth, mHeight, GL_RGBA, GL_UNSIGNED_BYTE, mVideoBuffer.data());	// part of the texture aktualisieren
    mShader.Bind();
    mShader.SetUniform("tint", mTint);
    glBindVertexArray(mVAO);
      glDrawArrays(GL_TRIANGLES, 0, mVertices.size()); // render texture
    glBindVertexArray(0);
    glBindTexture(GL_TEXTURE_2D, 0);
  }
protected:
  Shader mShader {&_binary_shader_glsl_start, &_binary_shader_glsl_end};
  GLuint mTexture {0}, mVAO {0}, mVBO {0};
  int mWidth, mHeight;
  std::vector<uint32_t> mVideoBuffer;
  glm::mat4 mProjMatrix;
  std::vector<glm::vec4> mVertices;
  glm::vec4 mTint {1.0f, 1.0f, 1.0f, 1.0f};
};

class TextScreen : public Display
{
public:
  TextScreen(const uint32_t* charset, int cols, int rows)
  : mCharsetPtr(charset), mCols(cols), mRows(rows), Display(cols<<3, rows<<3) {}
  ~TextScreen() {}
  void Goto(int x, int y) { mXCur = x; mYCur = y; }
	void Move(int dx, int dy) { mXCur += dx; mYCur += dy; }
  void Color(int cindex) { mColorIndex = cindex; }
  void Print(std::string text)
  {
    for (int i=0; i<text.length(); i++)
    {
      if (text[i] == '\n') { mXCur = 0; mYCur++; }
      else
      {
        uint32_t* vptr = mVideoBuffer.data() + (mYCur<<3)*mWidth + (mXCur<<3);
        if (mXCur < mCols && mYCur < mRows) // print only in visible area
        {
          int index = text[i]<<3; // index into charset
          for (int y=0; y<8; y++)
          {
            for (int x=0; x<8; x++) vptr[x] = mCharsetPtr[index + x] & mColors[mColorIndex];
            vptr += mWidth; index += 2048; // goto next row
          } 
        } 
        mXCur++; // advance cursor
      }
    }
  }
  void Print(int x, int y, int cindex, std::string text) { Goto(x, y); Color(cindex); Print(text); }
protected:
  const uint32_t* mCharsetPtr;
  int mCols, mRows;
  int mXCur {0}, mYCur {0}, mColorIndex {0};
  uint32_t mColors[10] { 0xffffffff, 0xff808080, 0xff0000ff, 0xff00ff00, 0xffff0000,   // 0: white, gray, red, green, blue, 
                         0xff00ffff, 0xffff00ff, 0xffffff00, 0xffff8080, 0xff8080ff }; // 5: yellow, magenta, cyan, lt blue, lt red
};
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
int main(int argc, char *argv[]) // OpenGL setup and launch of Application class
{
  if (glfwInit() == GLFW_FALSE) { std::cerr << "glfwInit() failed\n"; return 0; }
  glfwWindowHint(GLFW_CONTEXT_VERSION_MAJOR, 3);
  glfwWindowHint(GLFW_CONTEXT_VERSION_MINOR, 3);
  glfwWindowHint(GLFW_OPENGL_PROFILE, GLFW_OPENGL_CORE_PROFILE);
  glfwWindowHint(GLFW_SAMPLES, 0);

  GLFWmonitor* monitor = glfwGetPrimaryMonitor();
  const GLFWvidmode* mode = glfwGetVideoMode(monitor);
  float targetframetime = 1.0f/float(mode->refreshRate);

  if (mode == nullptr) { std::cerr << "glfwGetVideoMode() failed\n"; return 0; }
  glfwWindowHint(GLFW_RED_BITS, mode->redBits);
  glfwWindowHint(GLFW_GREEN_BITS, mode->greenBits);
  glfwWindowHint(GLFW_BLUE_BITS, mode->blueBits);
  glfwWindowHint(GLFW_REFRESH_RATE, mode->refreshRate);

  GLFWwindow* win = glfwCreateWindow(mode->width, mode->height, "OpenGL", monitor, nullptr); // FULLSCREEN: monitor, WINDOWED: nullptr
  if (win == nullptr) { std::cerr << "glfwCreateWindow() failed\n"; glfwTerminate(); return 0; } // glfwTerminate() is new
  glfwMakeContextCurrent(win);
  glfwSwapInterval(1); // acts on current context
  glfwSetInputMode(win, GLFW_CURSOR, GLFW_CURSOR_DISABLED);

  if (!gladLoadGLLoader((GLADloadproc)glfwGetProcAddress)) // Init GLAD OpenGL-Extension-Loader BEFORE any OpenGL calls are made
  {
    std::cerr << "gladLoadGLLoader() failed\n";
    glfwDestroyWindow(win); glfwTerminate(); return 0;
  } 

  glDisable(GL_MULTISAMPLE);
  glEnable(GL_BLEND);
  glBlendFunc(GL_SRC_ALPHA, GL_ONE_MINUS_SRC_ALPHA); // normal blending
  glBlendEquation(GL_FUNC_ADD);
  glDisable(GL_DEPTH_TEST); // disable depth-testing
  glDepthMask(GL_FALSE); // disable writing to depth buffer

  try // exceptions are thrown by the application to report errors during display setup, shader loading etc.
  {
    float lasttime = float(glfwGetTime());
    Application app(win, targetframetime, argc, argv); // create main application
    while (app.isRunning()) // MAIN LOOP OF APPLICATION
    {
      float akttime = float(glfwGetTime());
      float deltat = akttime - lasttime;
      lasttime = akttime;
      glfwPollEvents(); // update event loop
      app.ProcessInput(); // injects keypresses      
      app.Update(akttime, deltat); // injects time
      glDepthMask(GL_TRUE); // enable write to depth buffer, das muss vor glClear passieren!
      glClear(GL_COLOR_BUFFER_BIT | GL_DEPTH_BUFFER_BIT); // colors are cleared, stencil and z buffer could also be cleared
      app.Render();
      glfwSwapBuffers(win);
      if (deltat < 0.5f * targetframetime) std::this_thread::sleep_for(std::chrono::milliseconds(1)); // catch disabled VSYNC
    }
  }
  catch (const std::exception& e) { std::cerr << e.what() << std::endl; }
  catch (...) { std::cerr << "Unknown app exception\n"; }

  glfwDestroyWindow(win); // close OpenGL window first
  glfwTerminate(); // destroy context, window and all other OpenGL stuff
  return 0;
}

/*
  LICENSING INFORMATION
  ---------------------
  This file is free software: you can redistribute it and/or modify it under the terms of the
  GNU General Public License as published by the Free Software Foundation, either
  version 3 of the License, or (at your option) any later version.
  
  This file is distributed in the hope that it will be useful, but WITHOUT ANY WARRANTY; without even the
  implied warranty of MERCHANTABILITY or FITNESS FOR A PARTICULAR PURPOSE. See the GNU General Public
  License for more details. You should have received a copy of the GNU General Public License along
  with this program. If not, see https://www.gnu.org/licenses/.
*/

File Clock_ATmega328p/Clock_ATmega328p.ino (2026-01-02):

// ATmega328P (16MHz) adjustable clock generator for the Minimal UART Computer 3 written by Carsten Herting (slu4) 2025
// This software allows to control the CPU frequency (single step - 8MHz) and the UART rate via two pushbuttons (SELECT, SINGLE)
// See more information on the PCB layout of the Minimal UART Computer 3

// CPU rate      8MHz       1MHz       100kHz     10kHz      1kHz       100Hz      10Hz                 1Hz
int ocr[8] = {   0,         7,         79,        799,       7999,      9999,      12499,               31249     };
int pre[8] = {  _BV(CS10), _BV(CS10), _BV(CS10), _BV(CS10), _BV(CS10), _BV(CS11), _BV(CS11)|_BV(CS10), _BV(CS12) }; // prescale 1, 1, 1, 1, 1, 8, 64, 256

// UART rate     0: 500kbps, 1: 250kbps, 3: 125kbps, 4: 100kbps, 7: 62.5kbps, 12: 38.4kbps, 25: 19.2kbps, 51: 9.6kbps
int uart_ocr[8] = { 0, 1, 3, 4, 7, 12, 25, 51 };

int clkstate = 0; // initial clock state: 8MHz
int uartstate = 2; // initial UART bitrate: 125kbps
bool single = false; // single-step mode on/off
bool showuart = false; // show UART state (blinking LEDs) on/off
bool showexit = false; // indicates leaving 'showuart' state

void setup()
{  
  DDRB  = 0b00001010; // pins 8-13 (9: CPU_OSC via OC1A, 11: UART_OSC via OC2A)
  PORTB = 0b00000101; // 20k pull-up on pins 8 ( and 10 for buttons

  // UART clock (bit rate = UART_CLK / 16)
  TCCR2A = _BV(COM2A0) | _BV(WGM21);  // Toggle OC2A for UART (pin 11)
  TCCR2B = _BV(CS20);                 // CTC, Prescaler 1
  OCR2A = uart_ocr[uartstate];

  // CPU clock (CLK)
  TCCR1A = _BV(COM1A0);               // Toggle OC1A for CLK (pin 9)333
  TCCR1B = _BV(WGM12) | pre[clkstate];
  OCR1A  = ocr[clkstate];

  // use pins A0-A2 to indicate clock clkstate
  DDRC  = 0b00000111;
  PORTC = clkstate;
}

#define BUTTON_IS_NONE    0
#define BUTTON_IS_MODE    1
#define BUTTON_IS_UART    2

int SelectButton()
{
  static bool selectstate = false;

  int m = 0; int s = 0;
  for (int i=0; i<50; i++)
  {
    m += bool(PINB & 0b00000100); // sample MODE SELECT button
    s += bool(PINB & 0b00000001); // sample SINGLE STEP button
  }

  if (m > 45) // MODE SELECT isn't pressed or was released
  {
    if (selectstate == false) return BUTTON_IS_NONE;
    else { selectstate = false; delay(5); return BUTTON_IS_NONE; }
  }
  
  if (m < 5)
  {
    if (selectstate == true) return BUTTON_IS_NONE; // key was already pressed => no new keypress
    else
    {
      selectstate = true; // key wasn't pressed before => report new keypress
      delay(5);
      if (s < 5) return BUTTON_IS_UART; else return BUTTON_IS_MODE;
    }
  }
  return BUTTON_IS_NONE;
}

void loop()
{  
  if (single == true) // case "single step mode"
  {
    if (showuart == false)
    {
      int b = SelectButton();
      if (b == BUTTON_IS_MODE) { TCCR1A |= _BV(COM1A0); single = false; } // turn clock on
      else if (b == BUTTON_IS_UART) { showuart = true; delay (5); } // enter uart mode
      else // BUTTON_IS_NONE
      {
        int z = 0; for (int i=0; i<50; i++) z += bool(PINB & 0b00000001);
        if (z > 45) { bitWrite(PORTB, 1, HIGH); delay (5); }
        else if (z < 5) { bitWrite(PORTB, 1, LOW); delay(5); }
      }
    }
    else // showuart == true
    {
      if (SelectButton() == BUTTON_IS_UART)
      {
        delay(5);
        uartstate = (uartstate + 1) & 7;
        PORTC = uartstate;
        OCR2A = uart_ocr[uartstate];
      }
      if ((millis() & 127) > 64) PORTC = uartstate; else PORTC = 0;
      int z = 0; for (int i=0; i<50; i++) z += bool(PINB & 0b00000001); // read SINGLE button
      if (z > 45) { showuart = false; TCCR1A |= _BV(COM1A0); single = false; PORTC = clkstate; delay(5); } // go back and restart clock
    }
  }
  else // single == false
  {
    if ((PINB & 0b00000001) == 0) { TCCR1A &= ~_BV(COM1A0); delay(5); single = true; } // clock off
    else if (SelectButton() == BUTTON_IS_MODE)
    {
      clkstate = (clkstate + 1) & 7; // rotate clkstate
      PORTC = clkstate;
      TCCR1B = _BV(WGM12) | pre[clkstate]; // set CTC and Prescaler
      OCR1A  = ocr[clkstate]; // set timer
    }      
  }
}

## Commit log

2025-12-30 Revise README for Minimal UART Computer update
    Updated README to reflect new features and resources.
2026-01-05 Add reference to 'Emulator' section in readme
    Added a note to refer to the 'Emulator' section for assembler source code.
2026-01-24 Fixing a bug in F2 CPU status display
    [main.cpp]
2026-06-29 Update title to 'Minimal UART Computer 3'

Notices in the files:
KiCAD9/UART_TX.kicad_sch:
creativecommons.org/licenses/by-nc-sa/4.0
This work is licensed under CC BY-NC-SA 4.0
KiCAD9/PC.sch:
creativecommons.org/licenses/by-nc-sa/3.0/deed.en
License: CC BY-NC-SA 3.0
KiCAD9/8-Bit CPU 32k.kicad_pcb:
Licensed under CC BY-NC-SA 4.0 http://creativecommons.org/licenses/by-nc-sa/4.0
